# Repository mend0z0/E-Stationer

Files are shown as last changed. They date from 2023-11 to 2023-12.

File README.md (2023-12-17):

## Latest update

``
Working on the scheduling, hardware design, correcting diagrams, and...
``

# E-Stationer

E-Stationer is a project of consisting of two hardware parts, E-Pen and E-Paper, and 1 software parts that allow the user
to draw, write, read, and any sort of activities that you are able to do with a typical pen and paper.

## Features

- 
- 
- 

## Tech Stack

### Hardware

- **MCU:** 8bit PIC

- **Connection:** USB, UART, SPI, ADC, GPIO

- **PCB Layers:** 2Layers (None-controlled Impedance)

- **CAD:** KiCAD

### Firmware

- **OS:** State-machine

- **Programming Language:** C

- **IDE:** MPLABX IDE

### Application

- **Application:** Qt6

## WBS Chart

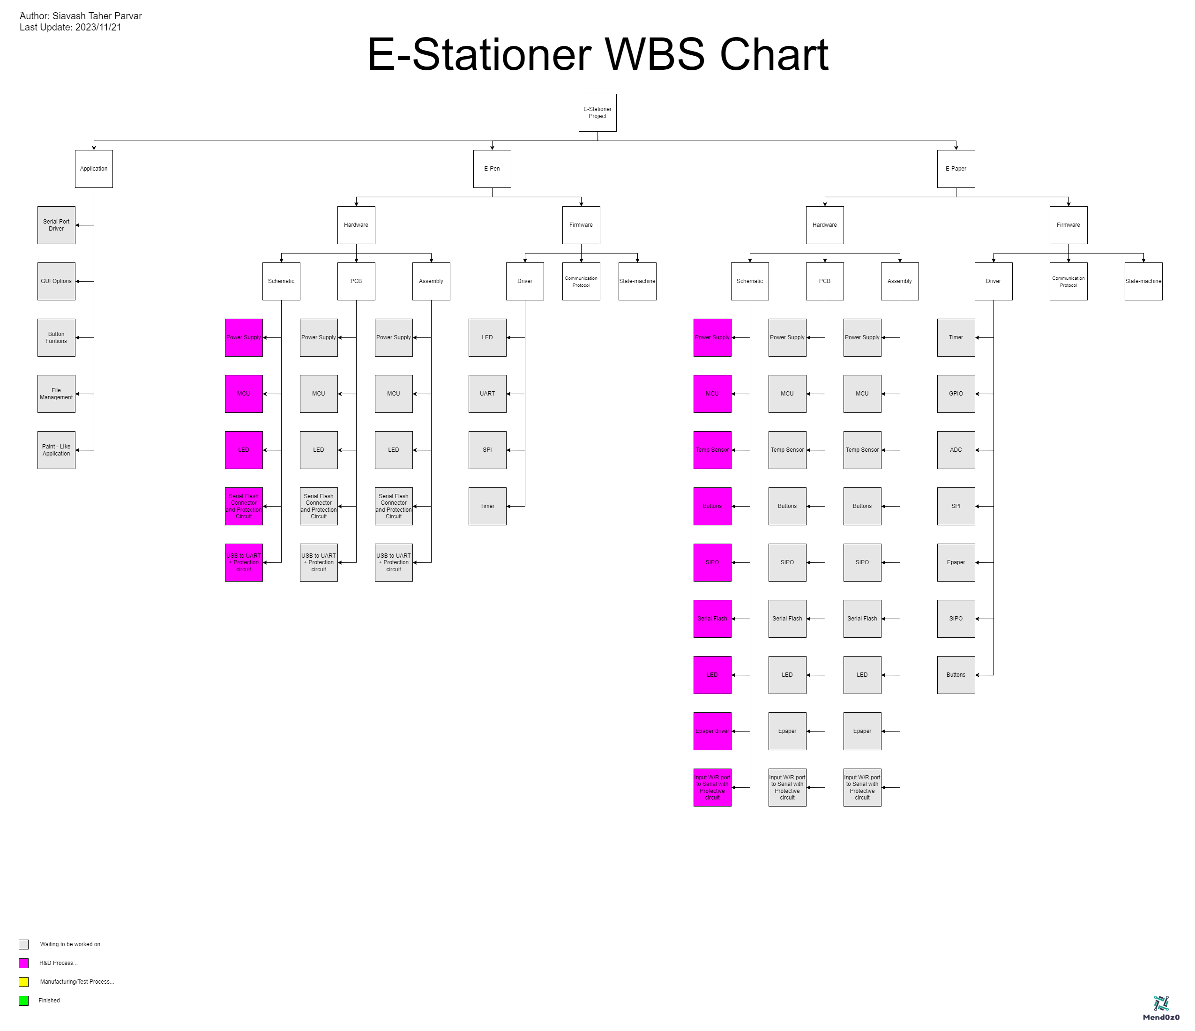
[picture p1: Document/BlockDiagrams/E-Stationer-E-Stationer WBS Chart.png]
WBS Chart


## Block Diagrams

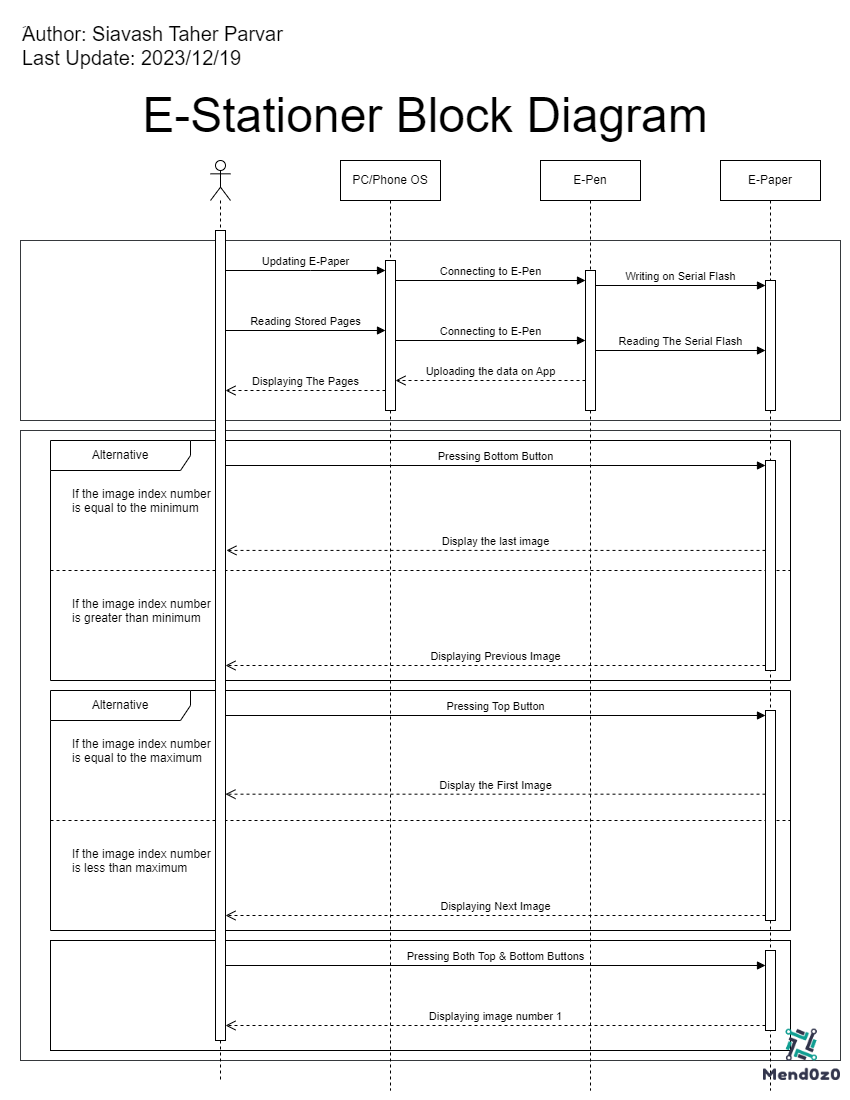
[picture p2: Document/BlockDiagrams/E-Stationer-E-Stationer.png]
E-Stationer Bloc kDiagaram


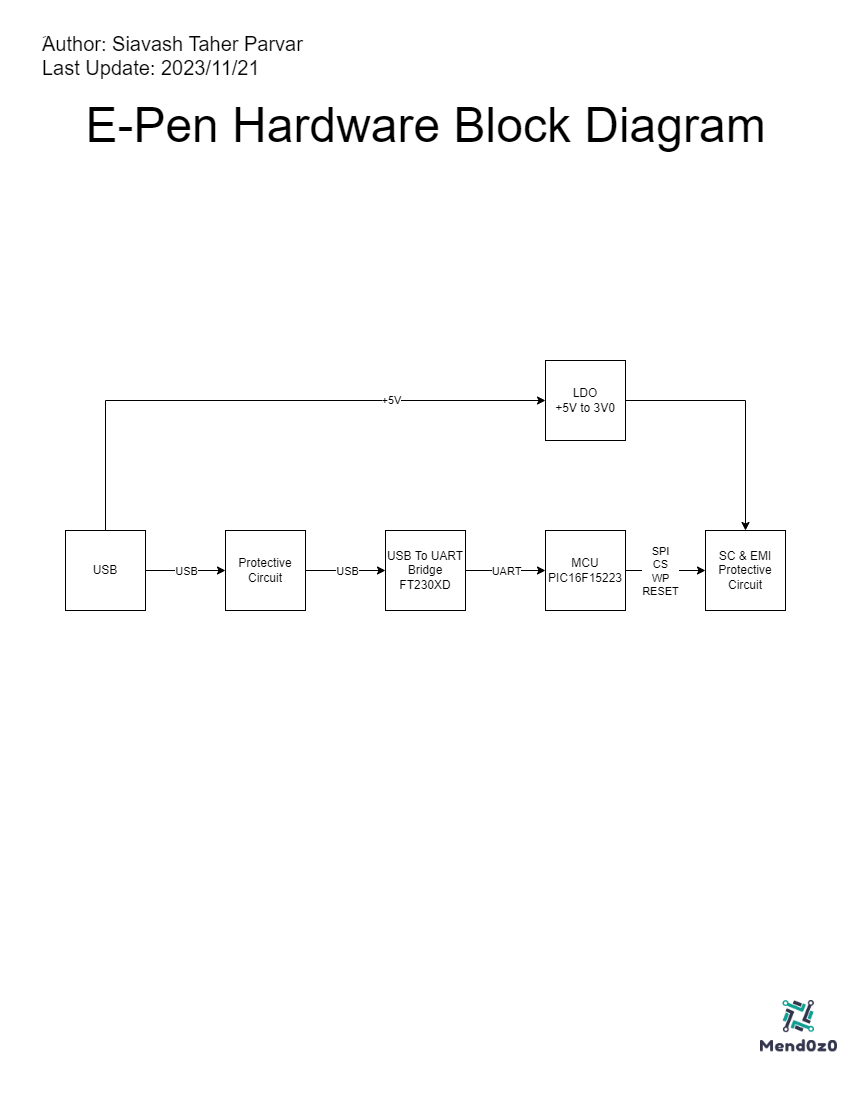
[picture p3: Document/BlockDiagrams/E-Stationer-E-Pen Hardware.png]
E-Pen Hardware Block Diagram


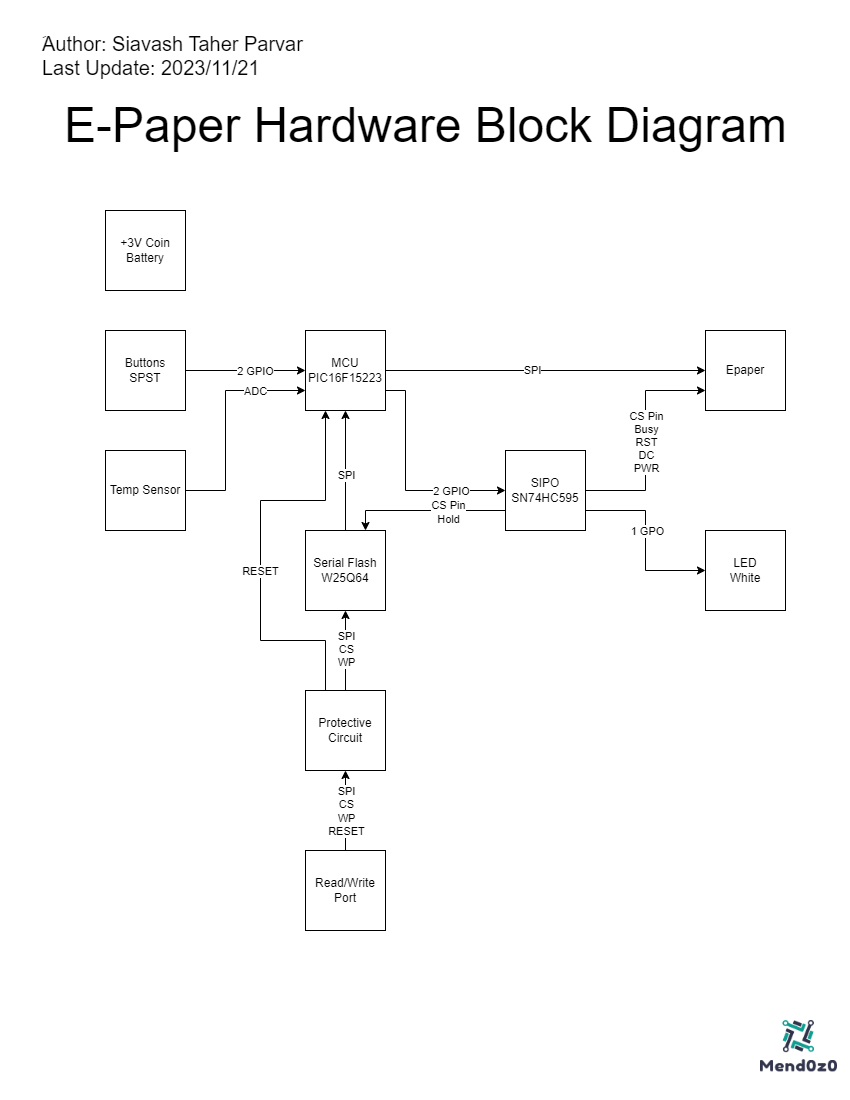
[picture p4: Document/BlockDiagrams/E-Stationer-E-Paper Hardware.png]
E-Paper Hardware Block Diagram


## Screenshots

### Hardware

#### 3D_View

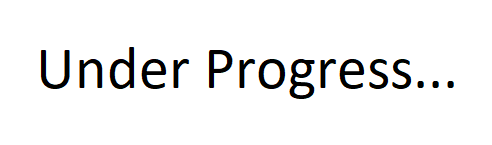
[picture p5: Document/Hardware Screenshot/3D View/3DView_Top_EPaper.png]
3DView_Top_EPaper


3DView_Bottom_EPaper

3DView_Top_EPen

3DView_Bottom_EPen
 
#### Assembled Hardware

Hardware_Top_EPaper

Hardware_Bottom_EPaper

Hardware_Top_EPen

Hardware_Bottom_EPen

### Application
App Screenshot

## Demo

Insert gif or link to demo, it'll be my youtube channel

## LOGO

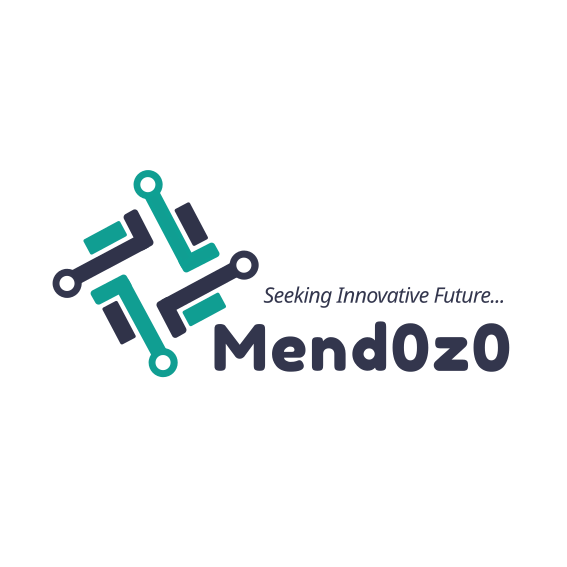
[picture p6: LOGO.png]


## Author

- [@Siavash Taher Parvar](https://www.linkedin.com/in/mend0z0)

## Support

[Support Link](https://github.com/sponsors/mend0z0)

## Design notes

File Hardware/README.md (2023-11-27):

# _SUB_HW_EPaper

- __What is this board?__ This board will display the stored picture on the serial flash eeprom.
- __How will this board communicate?__ This eeprom on this board will be programmed by provided SPI pin. While it's under programming the MCU will be kept at reset state.

## Features

- __MCU :__ PIC16F15223 
- __Inputs :__ SPI
- __Outputs :__ E-ink Display
- __Board Osc. Freq. :__ 32 MHz (Internal)
- __Working Voltage :__ 3VDC (Coin battery)
- __Current Consumption :__ N/A
- __Board Dimensions :__ N/A

# _SUB_HW_EPen

- __What is this board?__ This board will be used to write on the EPaper serial flash.
- __How will this board communicate?__ The data that has to be written on Epaper serial flash will be received from USB and it'll be written over SPI bus.

## Features

- __MCU :__ PIC16F15223 
- __Inputs :__ USB
- __Outputs :__ SPI
- __Board Osc. Freq. :__ 32 MHz (Internal)
- __Working Voltage :__ 5.5VDC (Powered by USB)
- __Current Consumption :__ N/A
- __Board Dimensions :__ N/A

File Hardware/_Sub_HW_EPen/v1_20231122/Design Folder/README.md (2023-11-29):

# TODO list

This todo list belongs to _SUB_HW_EPen, the hardware part of EPen sub project. 

## Tasks

- #### MUST to DO :
    - Writing the LED indicator status once it's been determined how it should blink based on different situation.
    - Adding proper screw component and link in mechanical page
    - Adding a good enclosure 
	- Adding the PCB and it's size to mechanical page
	- Adding 3D model for USB footprint (P/N: 10118194-0001LF) 
- #### Important :
    - List the works that efficient and optimized functionality of project depends on these tasks
    -
    - 
- #### General :
    - List tasks that are good to be done but the functionality of project doesn't depend on these
    -
    -

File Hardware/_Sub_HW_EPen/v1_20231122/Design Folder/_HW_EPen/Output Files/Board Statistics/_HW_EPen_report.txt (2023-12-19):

PCB statistics report
=====================
- Date: 12/19/2023 7:22:40 AM
- Project: _HW_EPen
- Board name: _HW_EPen

Board
-----
- Width: 1950.00 mils
- Height: 1150.00 mils
- Area: 2233839.53 mils²

Pads
----
- Through hole: 29
- SMD: 158
- Connector: 0
- NPTH: 0

Vias
----
- Through vias: 58
- Blind/buried: 0
- Micro vias: 0

Components
----------

| | Front Side | Back Side | Total |
|---|---|---|---|
|THT: | 2 | 0 | 2 |
|SMD: | 50 | 0 | 50 |
|Unspecified:  | 5 | 0 | 5 |
|Total: | 57 | 0 | 57 |

Drill holes
-----------

| Count | Shape | X Size | Y Size | Plated | Via/Pad | Start Layer | Stop Layer |
|---|---|---|---|---|---|---|---|
| 58 | Round |  15.75 mils |  15.75 mils | PTH | Via | F.Cu | B.Cu |
| 12 | Round |  39.37 mils |  39.37 mils | PTH | Pad | F.Cu | B.Cu |
| 9 | Round |  11.81 mils |  11.81 mils | PTH | Pad | F.Cu | B.Cu |
| 4 | Round | 106.30 mils | 106.30 mils | PTH | Pad | F.Cu | B.Cu |
| 2 |  Slot |  19.69 mils |  45.28 mils | PTH | Pad | F.Cu | B.Cu |
| 2 |  Slot |  33.46 mils |  21.65 mils | PTH | Pad | F.Cu | B.Cu |

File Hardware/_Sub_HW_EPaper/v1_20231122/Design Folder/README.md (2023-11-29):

# TODO list

A brief description of this todo list belongs to what project

## Tasks

- #### MUST to DO :
    - Adding 3D part to the 8-SOIC footprint for serial flash
    -
    - 
- #### Important :
    - List the works that efficient and optimized functionality of project depends on these tasks
    -
    - 
- #### General :
    - List tasks that are good to be done but the functionality of project doesn't depend on these
    -
    -

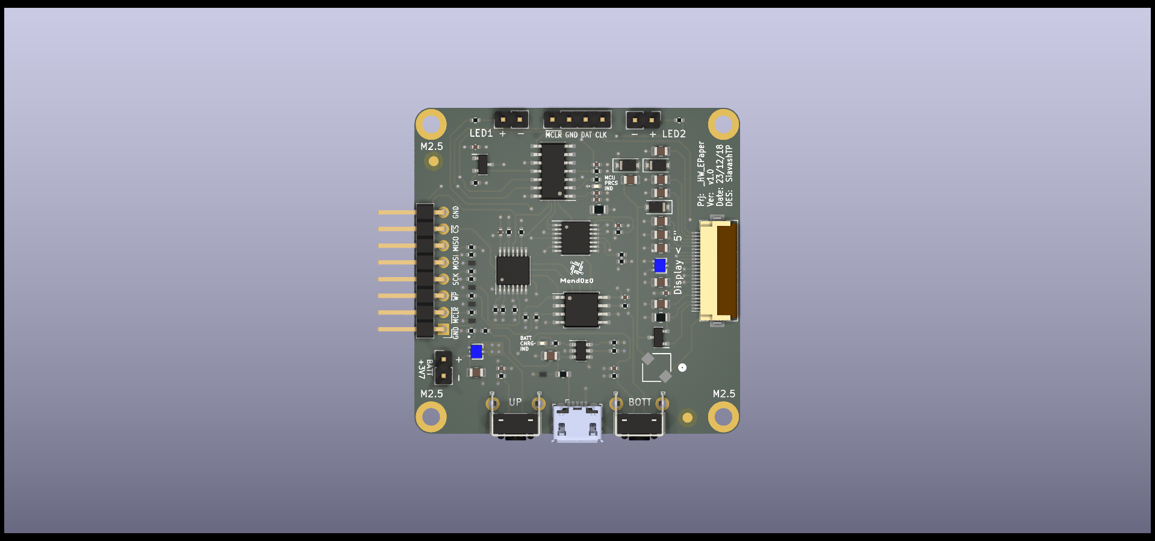
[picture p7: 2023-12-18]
Hardware/_Sub_HW_EPaper/v1_20231122/Released Folder/vX.Y - YYYYMMDD/3D/3D View Pic/_HW_EPaper_Top.png

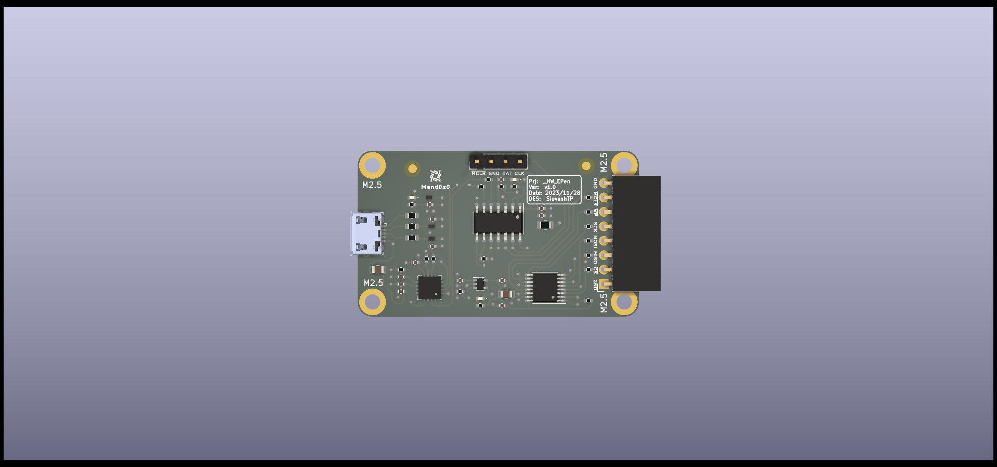
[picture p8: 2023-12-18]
Hardware/_Sub_HW_EPen/v1_20231122/Released Folder/vX.Y - YYYYMMDD/3D/3D View Pic/_HW_EPen_Top.png

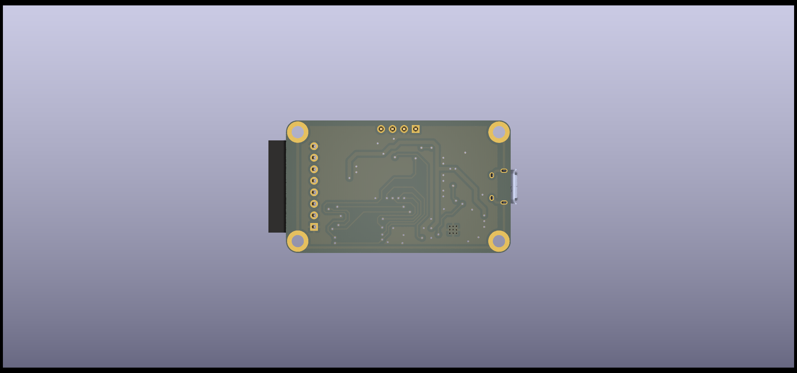
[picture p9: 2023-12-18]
Hardware/_Sub_HW_EPen/v1_20231122/Released Folder/vX.Y - YYYYMMDD/3D/3D View Pic/_HW_EPen_Bottom.png

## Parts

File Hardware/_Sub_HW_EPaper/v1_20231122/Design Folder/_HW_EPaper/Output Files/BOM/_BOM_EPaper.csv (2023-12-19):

null | Sourced | Placed | References | Value | Footprint | Link | Description | Manufacturer | Part Number (Manufacturer) | Part Number (Vendor) | Vendor | Quantity
1 |  |  | C701, C702, C704, C705, C706, C707, C708, C709, C710, C1001, C1002 | 4u7F_16V | C_0805_2012Metric | https://www.digikey.ca/en/products/detail/murata-electronics/GRM21BR71C475KE51L/6606095 | 4.7 µF ±10% 16V Ceramic Capacitor X7R 0805 (2012 Metric) | Murata Electronics | GRM21BR71C475KE51L | 490-14466-2-ND | Digikey | 11
2 |  |  | C302, C401, C501, C601, C801, C802, C901 | 1uF_10V_X7R | C_0402_1005Metric | https://www.digikey.ca/en/products/detail/murata-electronics/GRM155Z71A105KE01D/13905035 | 1 µF ±10% 10V Ceramic Capacitor X7R 0402 (1005 Metric) | Murata Electronics | GRM155Z71A105KE01D | 490-GRM155Z71A105KE01DTR-ND | Digikey | 7
3 |  |  | C301, C303, C703 | 100nF_50V | C_0402_1005Metric | https://www.digikey.ca/en/products/detail/murata-electronics/GRM155R71H104KE14J/4905180 | 0.1 µF ±10% 50V Ceramic Capacitor X7R 0402 (1005 Metric) | Murata Electronics | GRM155R71H104KE14J | 490-13342-2-ND | Digikey | 3
4 |  |  | R301, R401, R402, R403, R501, R502, R505, R506, R507, R508, R509, R601, R703, R801, R802, R901, R1003, R1005 | 10kR_1/16W_1% | R_0402_1005Metric | https://www.digikey.ca/en/products/detail/bourns-inc/CR0402-FX-1002GLF/3593192 | 10 kOhms ±1% 0.063W, 1/16W Chip Resistor 0402 (1005 Metric) Thick Film | Bourns Inc. | CR0402-FX-1002GLF | CR0402-FX-1002GLFTR-ND | Digikey | 18
5 |  |  | R503, R504, R510, R511 | 27R_1/16W_1% | R_0402_1005Metric | https://www.digikey.ca/en/products/detail/bourns-inc/CR0402-FX-27R0GLF/3783280 | 27 Ohms ±1% 0.063W, 1/16W Chip Resistor 0402 (1005 Metric) Thick Film | Bourns Inc. | CR0402-FX-27R0GLF | CR0402-FX-27R0GLFTR-ND | Digikey | 4
6 |  |  | R302, R702, R1004 | 470R_1/16W_1% | R_0402_1005Metric | https://www.digikey.ca/en/products/detail/bourns-inc/CR0402-FX-4700GLF/3783391 | 470 Ohms ±1% 0.063W, 1/16W Chip Resistor 0402 (1005 Metric) Thick Film | Bourns Inc. | CR0402-FX-4700GLF | CR0402-FX-4700GLFTR-ND | Digikey | 3
7 |  |  | R1001, R1101, R1102 | 100R_1/10W_1% | R_0402_1005Metric | https://www.digikey.ca/en/products/detail/koa-speer-electronics-inc/RK73H1ETTP1000F/9844157 | 100 Ohms ±1% 0.1W, 1/10W Chip Resistor 0402 (1005 Metric) Automotive AEC-Q200, Moisture Resistant Thick Film | KOA Speer Electronics, Inc. | RK73H1ETTP1000F | 2019-RK73H1ETTP1000FTR-ND | Digikey | 3
8 |  |  | R303 | 1R_1/4W_1% | R_0805_2012Metric | https://www.digikey.ca/en/products/detail/stackpole-electronics-inc/RNCP0805FTD1R00/2240195 | 1 Ohms ±1% 0.25W, 1/4W Chip Resistor 0805 (2012 Metric) Anti-Sulfur Thin Film | Stackpole Electronics Inc | RNCP0805FTD1R00 | RNCP0805FTD1R00TR-ND | Digikey | 1
9 |  |  | R701 | 0.47R_1/8W_5% | R_0805_2012Metric | https://www.digikey.ca/en/products/detail/cts-resistor-products/73L3R47J/1543464 | 470 mOhms ±5% 0.125W, 1/8W Chip Resistor 0805 (2012 Metric) Current Sense Thick Film | CTS Resistor Products | 73L3R47J | 73L3R47JTR-ND | Digikey | 1
10 |  |  | R1002 | 30kR_1/16W_1% | R_0402_1005Metric | https://www.digikey.ca/en/products/detail/bourns-inc/CR0402-FX-3002GLF/3783296 | 30 kOhms ±1% 0.063W, 1/16W Chip Resistor 0402 (1005 Metric) Thick Film | Bourns Inc. | CR0402-FX-3002GLF | CR0402-FX-3002GLFTR-ND | Digikey | 1
11 |  |  | L701 | 10uH_600mA | IND_CDRH3D11HPNP-100NC_SUM | https://www.digikey.ca/en/products/detail/sumida-america-inc/CDRH3D11HPNP-100NC/3947130 | 10 µH Shielded Inductor 600 mA 413mOhm Max Nonstandard | Sumida America Components Inc. | CDRH3D11HPNP-100NC | 308-1966-2-ND | Digikey | 1
12 |  |  | D501, D502, D503, D504, D1001 | TVS_6.5V_3A | CR_7PCT_L3F_TOS | https://www.digikey.ca/en/products/detail/good-ark-semiconductor/GSEWT5B003/18667485 | 20.5V Clamp 3A (8/20µs) Ipp Tvs Diode Surface Mount SOD-882 | Good-Ark Semiconductor | GSEWT5B003 | 4786-GSEWT5B003TR-ND | Digikey | 5
13 |  |  | D701, D702, D703 | SS2040FL | D_SOD-123F | https://www.digikey.ca/en/products/detail/panjit-international-inc/SS2040FL-R1-00001/14660034 | Diode 40 V 2A Surface Mount SOD-123FL | Panjit International Inc. | SS2040FL_R1_00001 | 3757-SS2040FL_R1_00001TR-ND | Digikey | 3
14 |  |  | U301 | PIC16F15223_8BIT | SO-14_3.9x8.65mm_P1.27mm | https://www.digikey.ca/en/products/detail/microchip-technology/PIC16F15223-E-SL/12807315 | PIC PIC® 16F, Functional Safety (FuSa) Microcontroller IC 8-Bit 32MHz 3.5KB (2K x 14) FLASH 14-SOIC | Microchip Technology | PIC16F15223-E/SL | 150-PIC16F15223-E/SL-ND | Digikey | 1
15 |  |  | U401 | W25Q64JVSSIQ | SOIC-8_5.275x5.275mm_P1.27mm | https://www.digikey.ca/en/products/detail/winbond-electronics/W25Q64JVSSIQ/5803992 | FLASH - NOR Memory IC 64Mbit SPI - Quad I/O 133 MHz 8-SOIC | Winbond Electronics | W25Q64JVSSIQ | W25Q64JVSSIQ-ND | Digikey | 1
16 |  |  | U501 | SN74HCS32PWR | TSSOP-14_4.4x5mm_P0.65mm | https://www.digikey.ca/en/products/detail/texas-instruments/SN74HCS32PWR/11625401 | OR Gate IC 4 Channel Schmitt Trigger Input 14-TSSOP | Texas Instruments | SN74HCS32PWR | 296-SN74HCS32PWRTR-ND | Digikey | 1
17 |  |  | U601 | 74VHC164FT | TSSOP-14_4.4x5mm_P0.65mm | https://www.digikey.ca/en/products/detail/toshiba-semiconductor-and-storage/74VHC164FT/5019930 | Shift Shift Register 1 Element 8 Bit 14-TSSOP | Toshiba Semiconductor and Storage | 74VHC164FT | 264-74VHC164FTTR-ND | Digikey | 1
18 |  |  | U901 | MCP9700T-E/TT | SOT-23 | https://www.digikey.ca/en/products/detail/microchip-technology/MCP9700T-E-TT/1212510 | Temperature Sensor Analog, Local -40°C ~ 125°C 10mV/°C SOT-23-3 | Microchip Technology | MCP9700T-E/TT | MCP9700T-E/TTTR-ND | Digikey | 1
19 |  |  | U1001 | RT9526AGE | SOT-23-6 | https://www.digikey.ca/en/products/detail/richtek-usa-inc/RT9526AGE/5820110 | Charger IC Lithium Ion SOT-23-6 | Richtek USA Inc. | RT9526AGE | 1028-1359-2-ND | Digikey | 1
20 |  |  | F1001 | 100mA_15V_0.5R | Fuse_0603_1608Metric | https://www.digikey.ca/en/products/detail/eaton-electronics-division/PTS060315V010/15193506 | PTC Resettable Fuse 15V 100 mA Ih Surface Mount 0603 (1608 Metric), Concave | Eaton - Electronics Division | PTS060315V010 | 283-PTS060315V010TR-ND | Digikey | 1
21 |  |  | SW801, SW802 | SPST-NO | SW_Tactile_SPST_Angled_PTS645Vx31-2LFS | https://www.digikey.ca/en/products/detail/c-k/PTS645VH31-2-LFS/1146771 | Tactile Switch SPST-NO Side Actuated Through Hole, Right Angle | C&K | PTS645VH31-2 LFS | CKN9118-ND | Digikey | 2
22 |  |  | LED301, LED1001 | RED_2V | LED_0402_1005Metric | https://www.digikey.ca/en/products/detail/harvatek-corporation/B2841USD-20D001014U1930/16729514 | Red 624nm LED Indication - Discrete 2V 0402 (1005 Metric) | Harvatek Corporation | B2841USD-20D001014U1930 | 3147-B2841USD-20D001014U1930TR-ND | Digikey | 2
23 |  |  | Q702, Q1001 | SSM3J117TU,LF | UFM_TOS | https://www.digikey.ca/en/products/detail/toshiba-semiconductor-and-storage/SSM3J117TU-LF/6679146 | P-Channel 30 V 2A (Ta) 500mW (Ta) Surface Mount UFM | Toshiba Semiconductor and Storage | SSM3J117TU,LF | SSM3J117TULFTR-ND | Digikey | 2
24 |  |  | Q701 | AS3400 | SOT-23 | https://www.digikey.ca/en/products/detail/anbon-semiconductor-int-l-limited/AS3400/16708476 | N-Channel 30 V 5.6A (Ta) 1.2W (Ta) Surface Mount SOT-23 | ANBON SEMICONDUCTOR (INT'L) LIMITED | AS3400 | 4530-AS3400TR-ND | Digikey | 1
25 |  |  | J1002, J1101, J1102 | HDR_2POS_VERT | PinHeader_1x02_P2.54mm_Vertical | https://www.digikey.ca/en/products/detail/adam-tech/PH1-02-UA/9830266 | Connector Header Through Hole 2 position 0.100" (2.54mm) | Adam Tech | PH1-02-UA | 2057-PH1-02-UA-ND | Digikey | 3
26 |  |  | J301 | HDR_4POS_VERT | PinHeader_1x04_P2.54mm_Vertical | https://www.digikey.ca/en/products/detail/adam-tech/PH1-04-UA/9829296 | Connector Header Through Hole 4 position 0.100" (2.54mm) | Adam Tech | PH1-04-UA | 2057-PH1-04-UA-ND | Digikey | 1
27 |  |  | J501 | HDR_8POS_RA | PinHeader_1x08_P2.54mm_Horizontal | https://www.digikey.ca/en/products/detail/adam-tech/PH1RB-08-UA/9831008 | Connector Header Through Hole, Right Angle 8 position 0.100" (2.54mm) | Adam Tech | PH1RB-08-UA | 2057-PH1RB-08-UA-ND | Digikey | 1
28 |  |  | J701 | FPC_24POS_BOTTOM_0.5P | Hirose_FH12-24S-0.5SH_1x24-1MP_P0.50mm_Horizontal | https://www.digikey.ca/en/products/detail/cvilux-usa/CF35242D0RD-NH/15793069 | 24 Position FFC, FPC Connector Contacts, Bottom 0.020" (0.50mm) Surface Mount, Right Angle | Cvilux USA | CF35242D0RD-NH | 2987-CF35242D0RD-NHTR-ND | Digikey | 1
29 |  |  | J1001 | USB_microB_RA | USB_Micro-B_Amphenol_10118194_Horizontal | https://www.digikey.ca/en/products/detail/amphenol-cs-fci/10118194-0001LF/2785389 | USB - micro B USB 2.0 Receptacle Connector 5 Position Surface Mount, Right Angle; Through Hole | Adam Tech | 10118194-0001LF | 2057-PH1RB-08-UA-ND | Digikey | 1

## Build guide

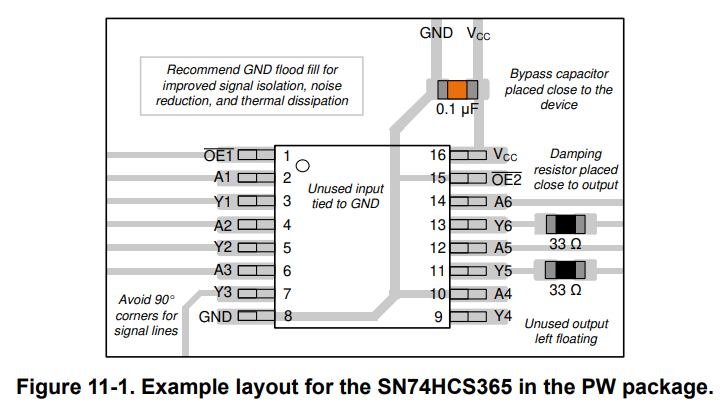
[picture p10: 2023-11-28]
Hardware/_Sub_HW_EPen/v1_20231122/Design Folder/Design Guides/Example layout for the SN74HCS365.png

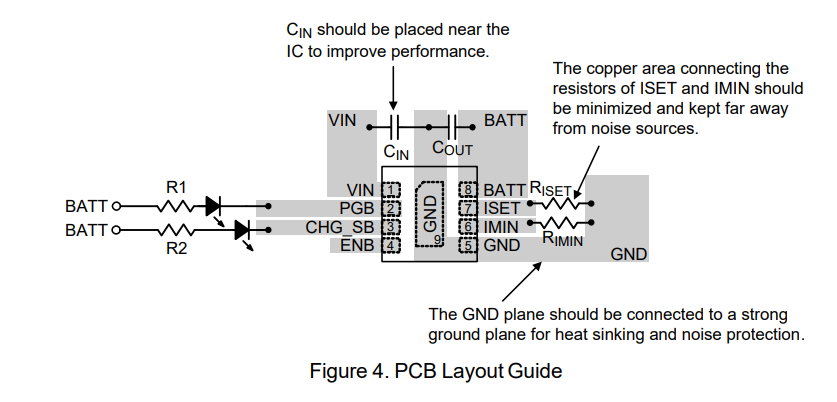
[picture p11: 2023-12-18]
Hardware/_Sub_HW_EPaper/v1_20231122/Design Folder/Design Guides/RT9526A_Layout.png

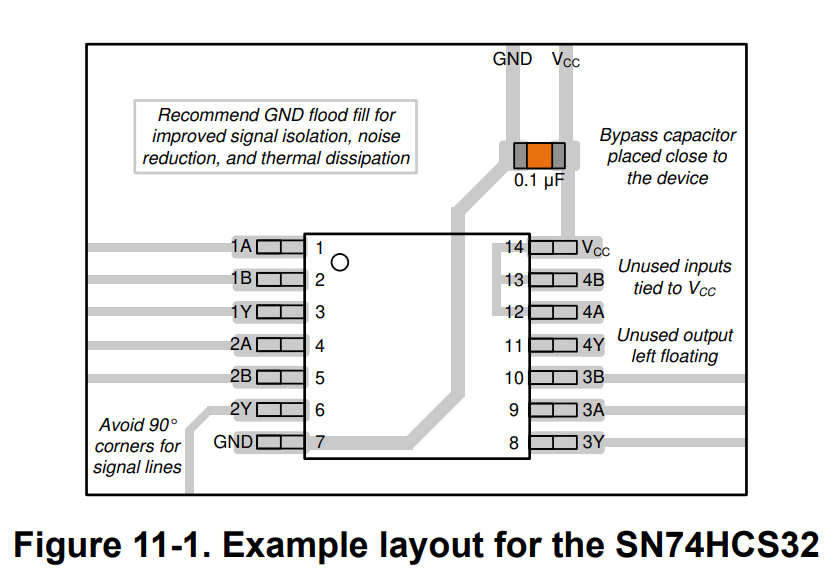
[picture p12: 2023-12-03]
Hardware/_Sub_HW_EPaper/v1_20231122/Design Folder/Design Guides/Screenshot_20231203_104745.png

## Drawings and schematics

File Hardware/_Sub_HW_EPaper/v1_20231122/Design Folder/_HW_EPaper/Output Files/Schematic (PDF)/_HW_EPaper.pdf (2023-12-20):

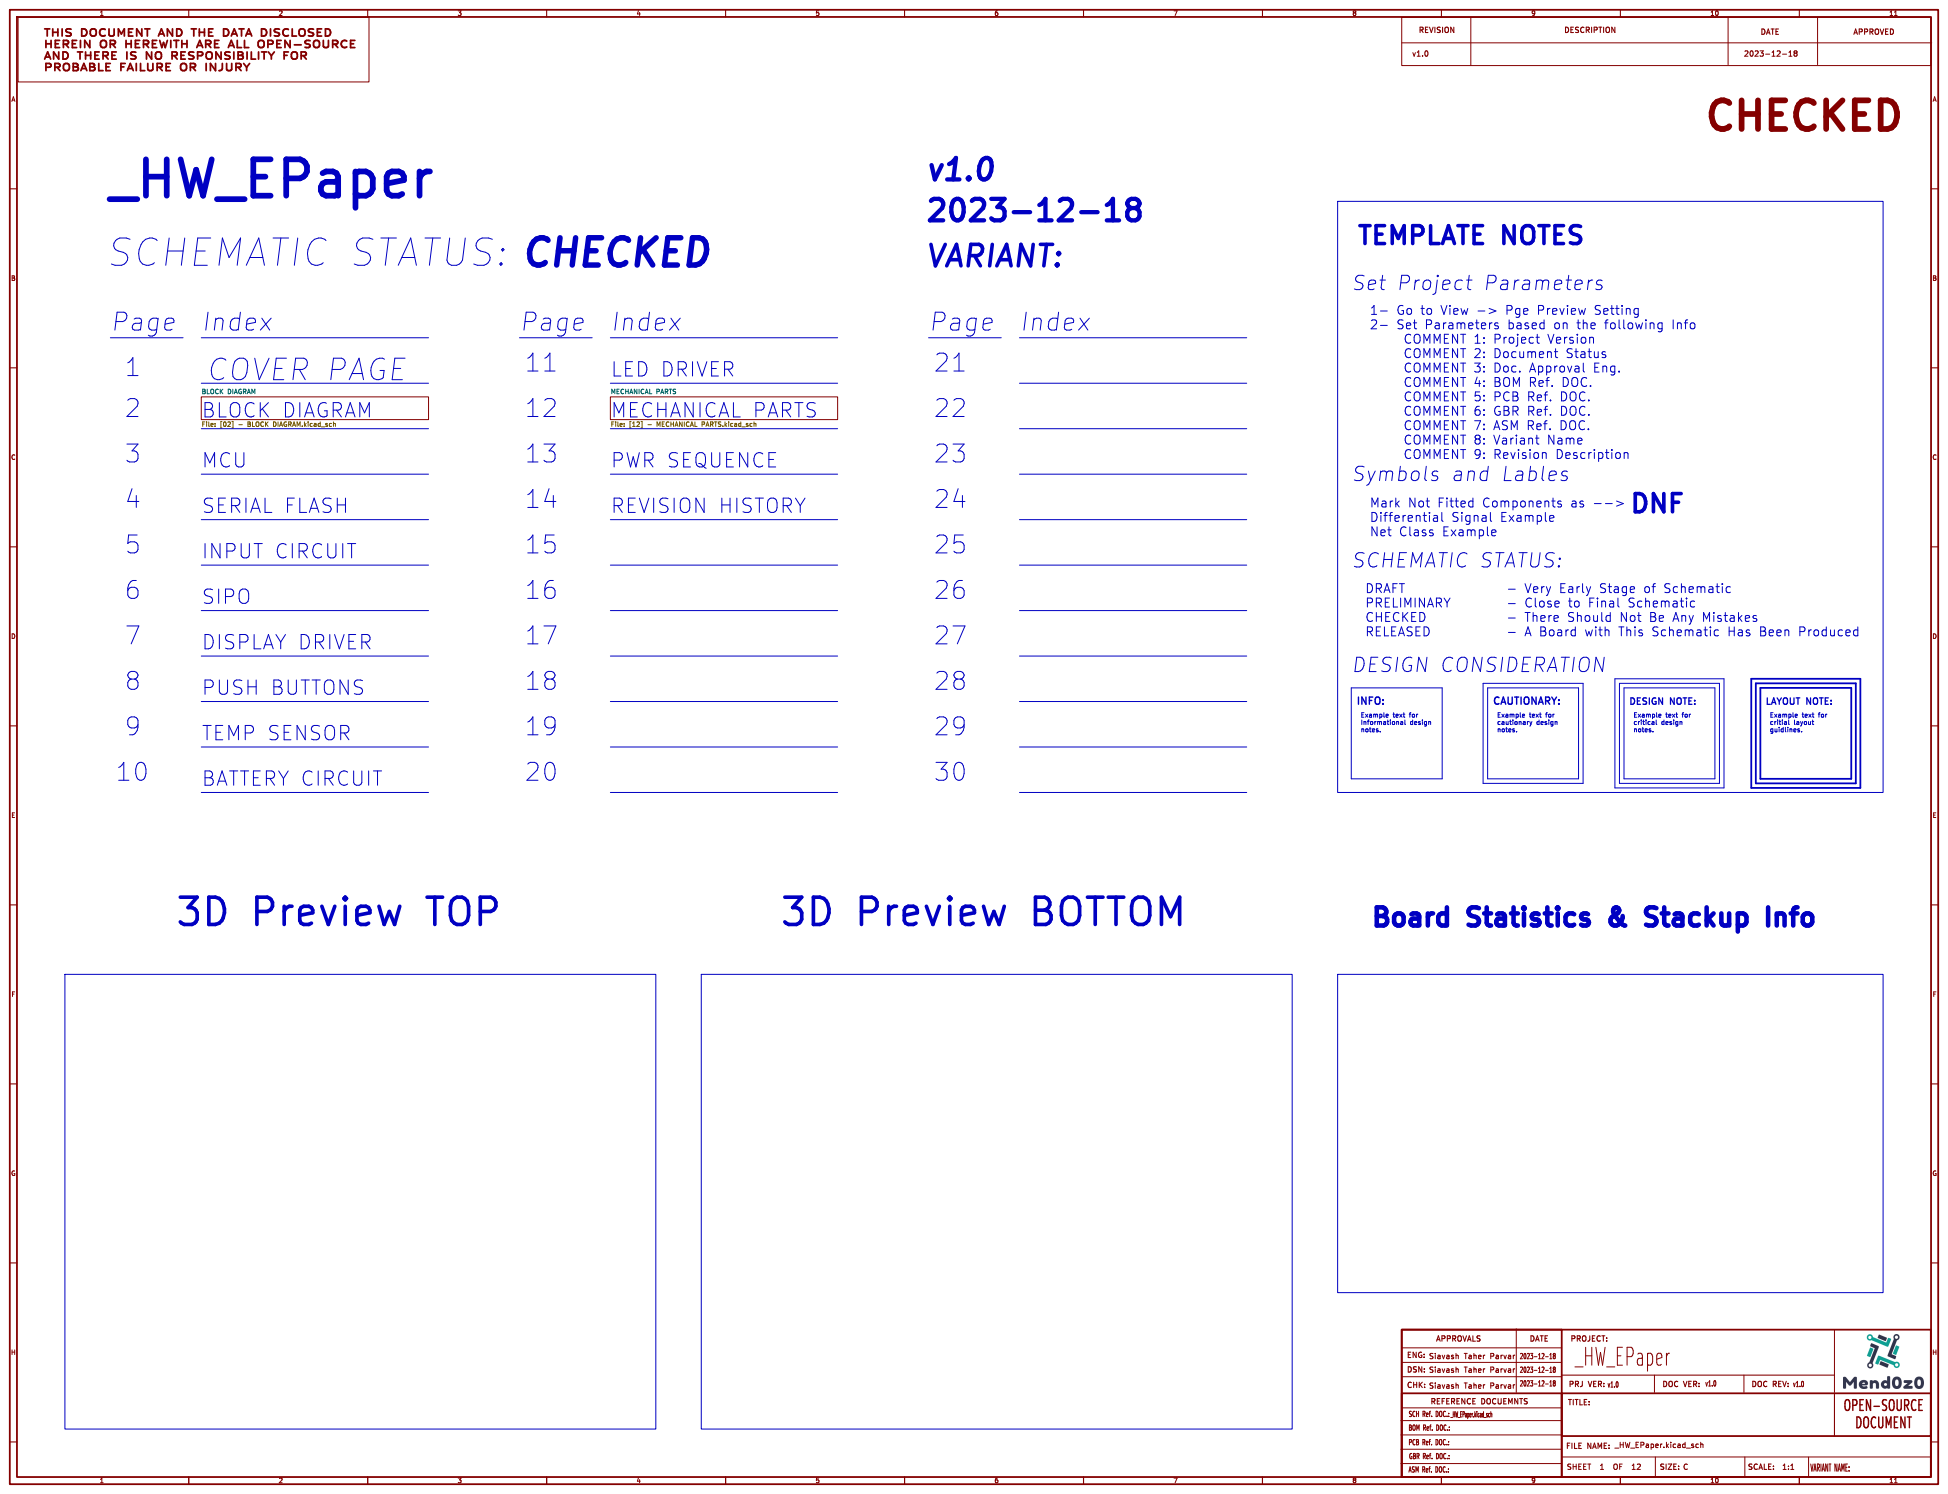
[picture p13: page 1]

1- Go to View -> Pge Preview Setting
Symbols and Lables

Mark Not Fitted Components as -->
Net Class Example
SCHEMATIC STATUS:

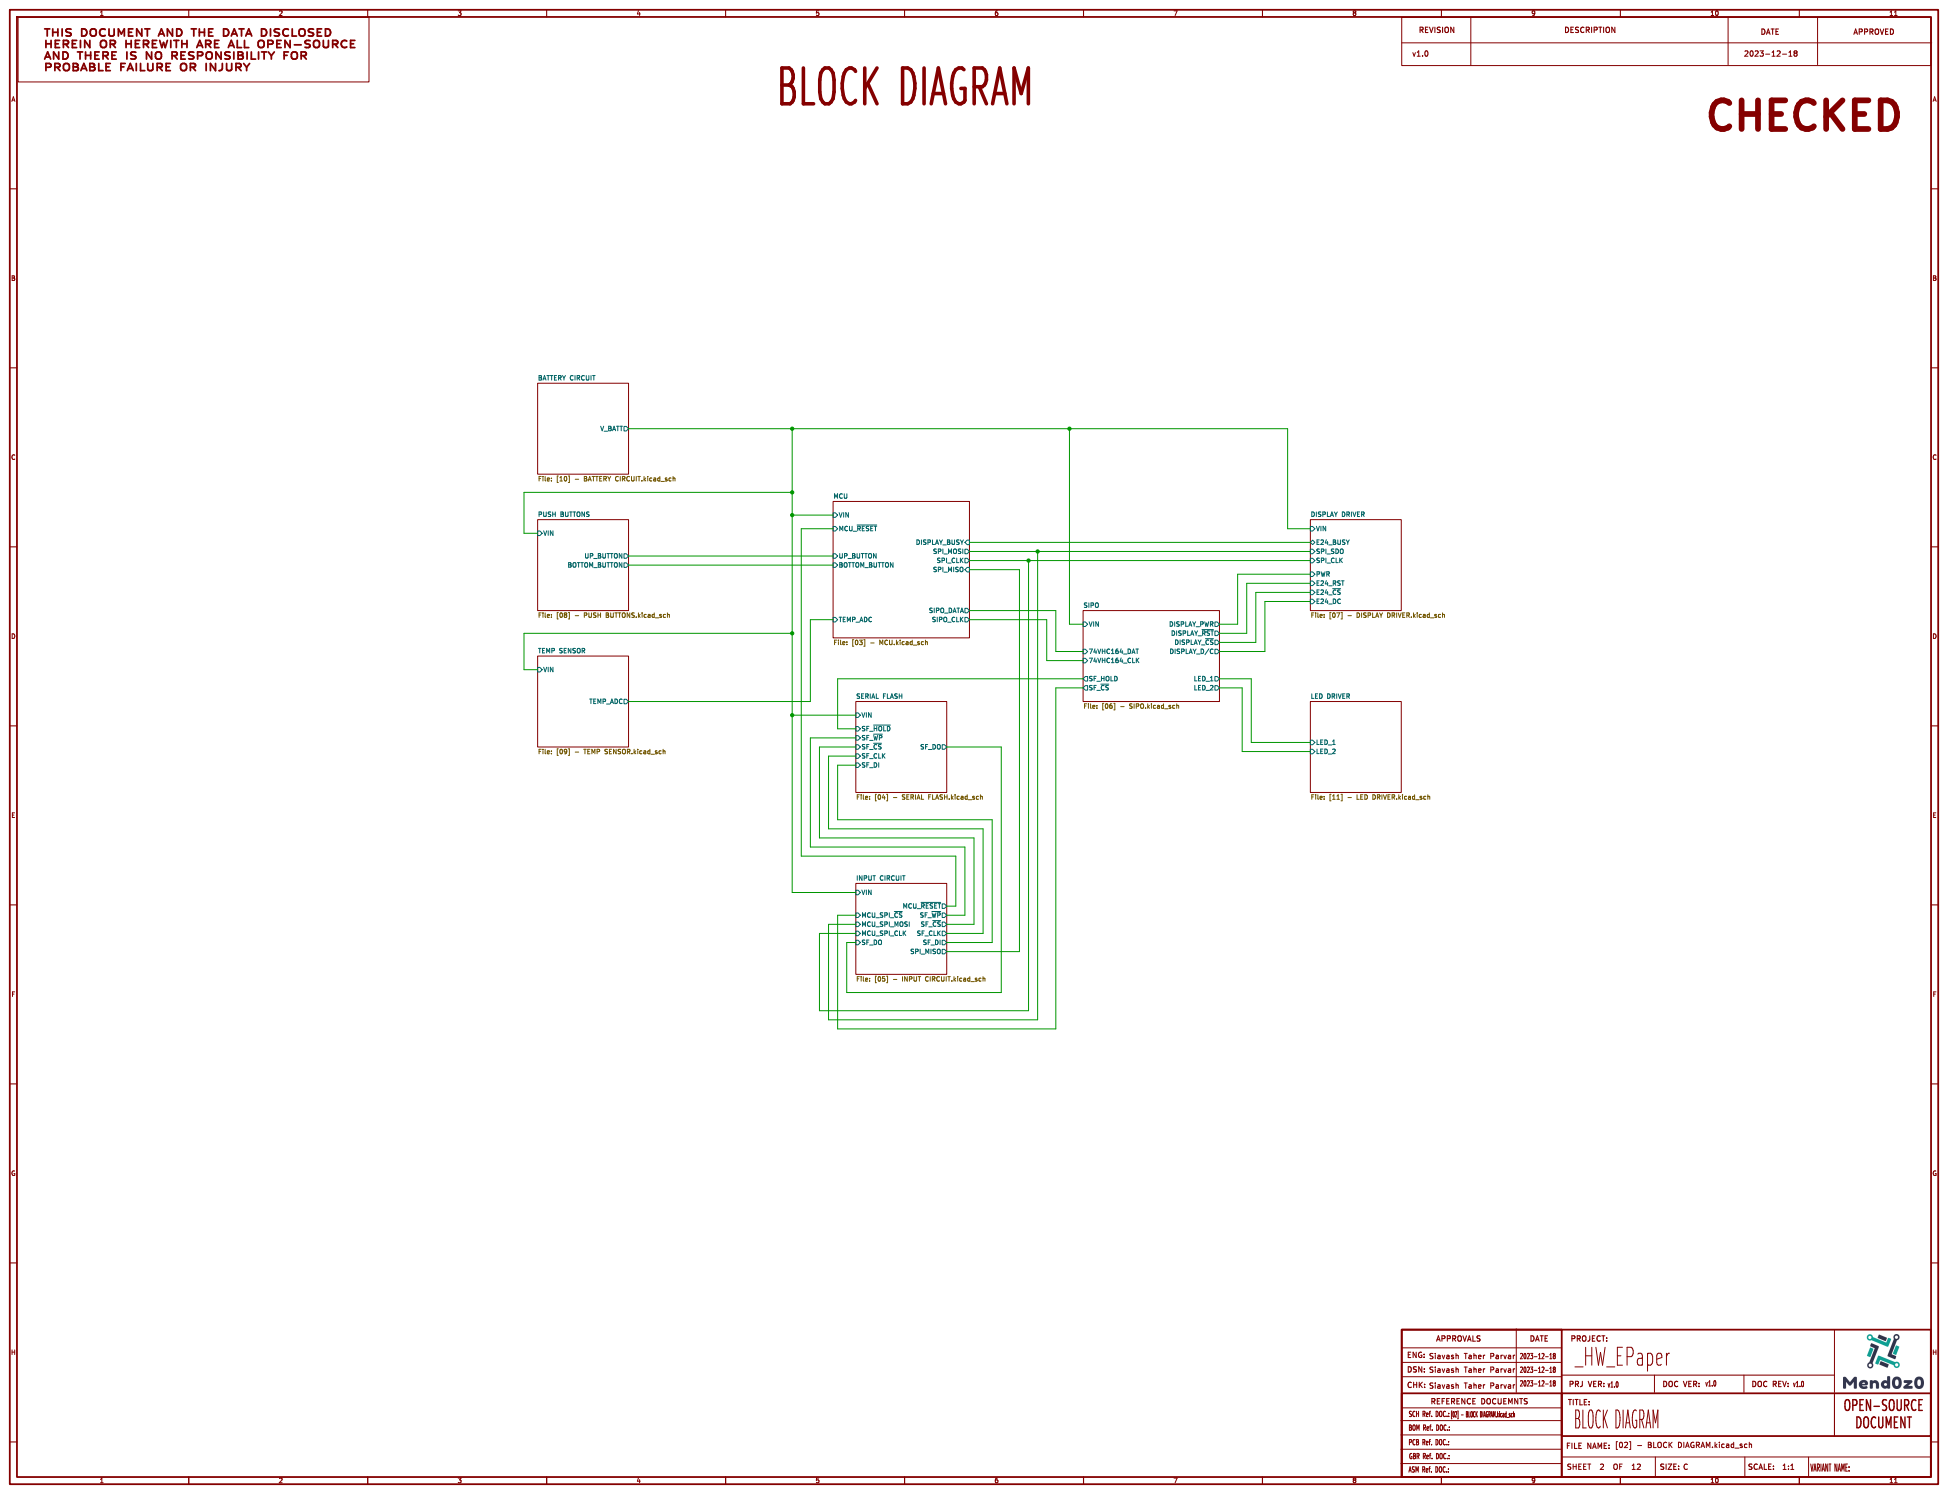
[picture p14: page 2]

File: [08] - PUSH BUTTONS.kicad_sch V_BATT BATTERY CIRCUIT

File: [04] - SERIAL FLASH.kicad_sch VIN

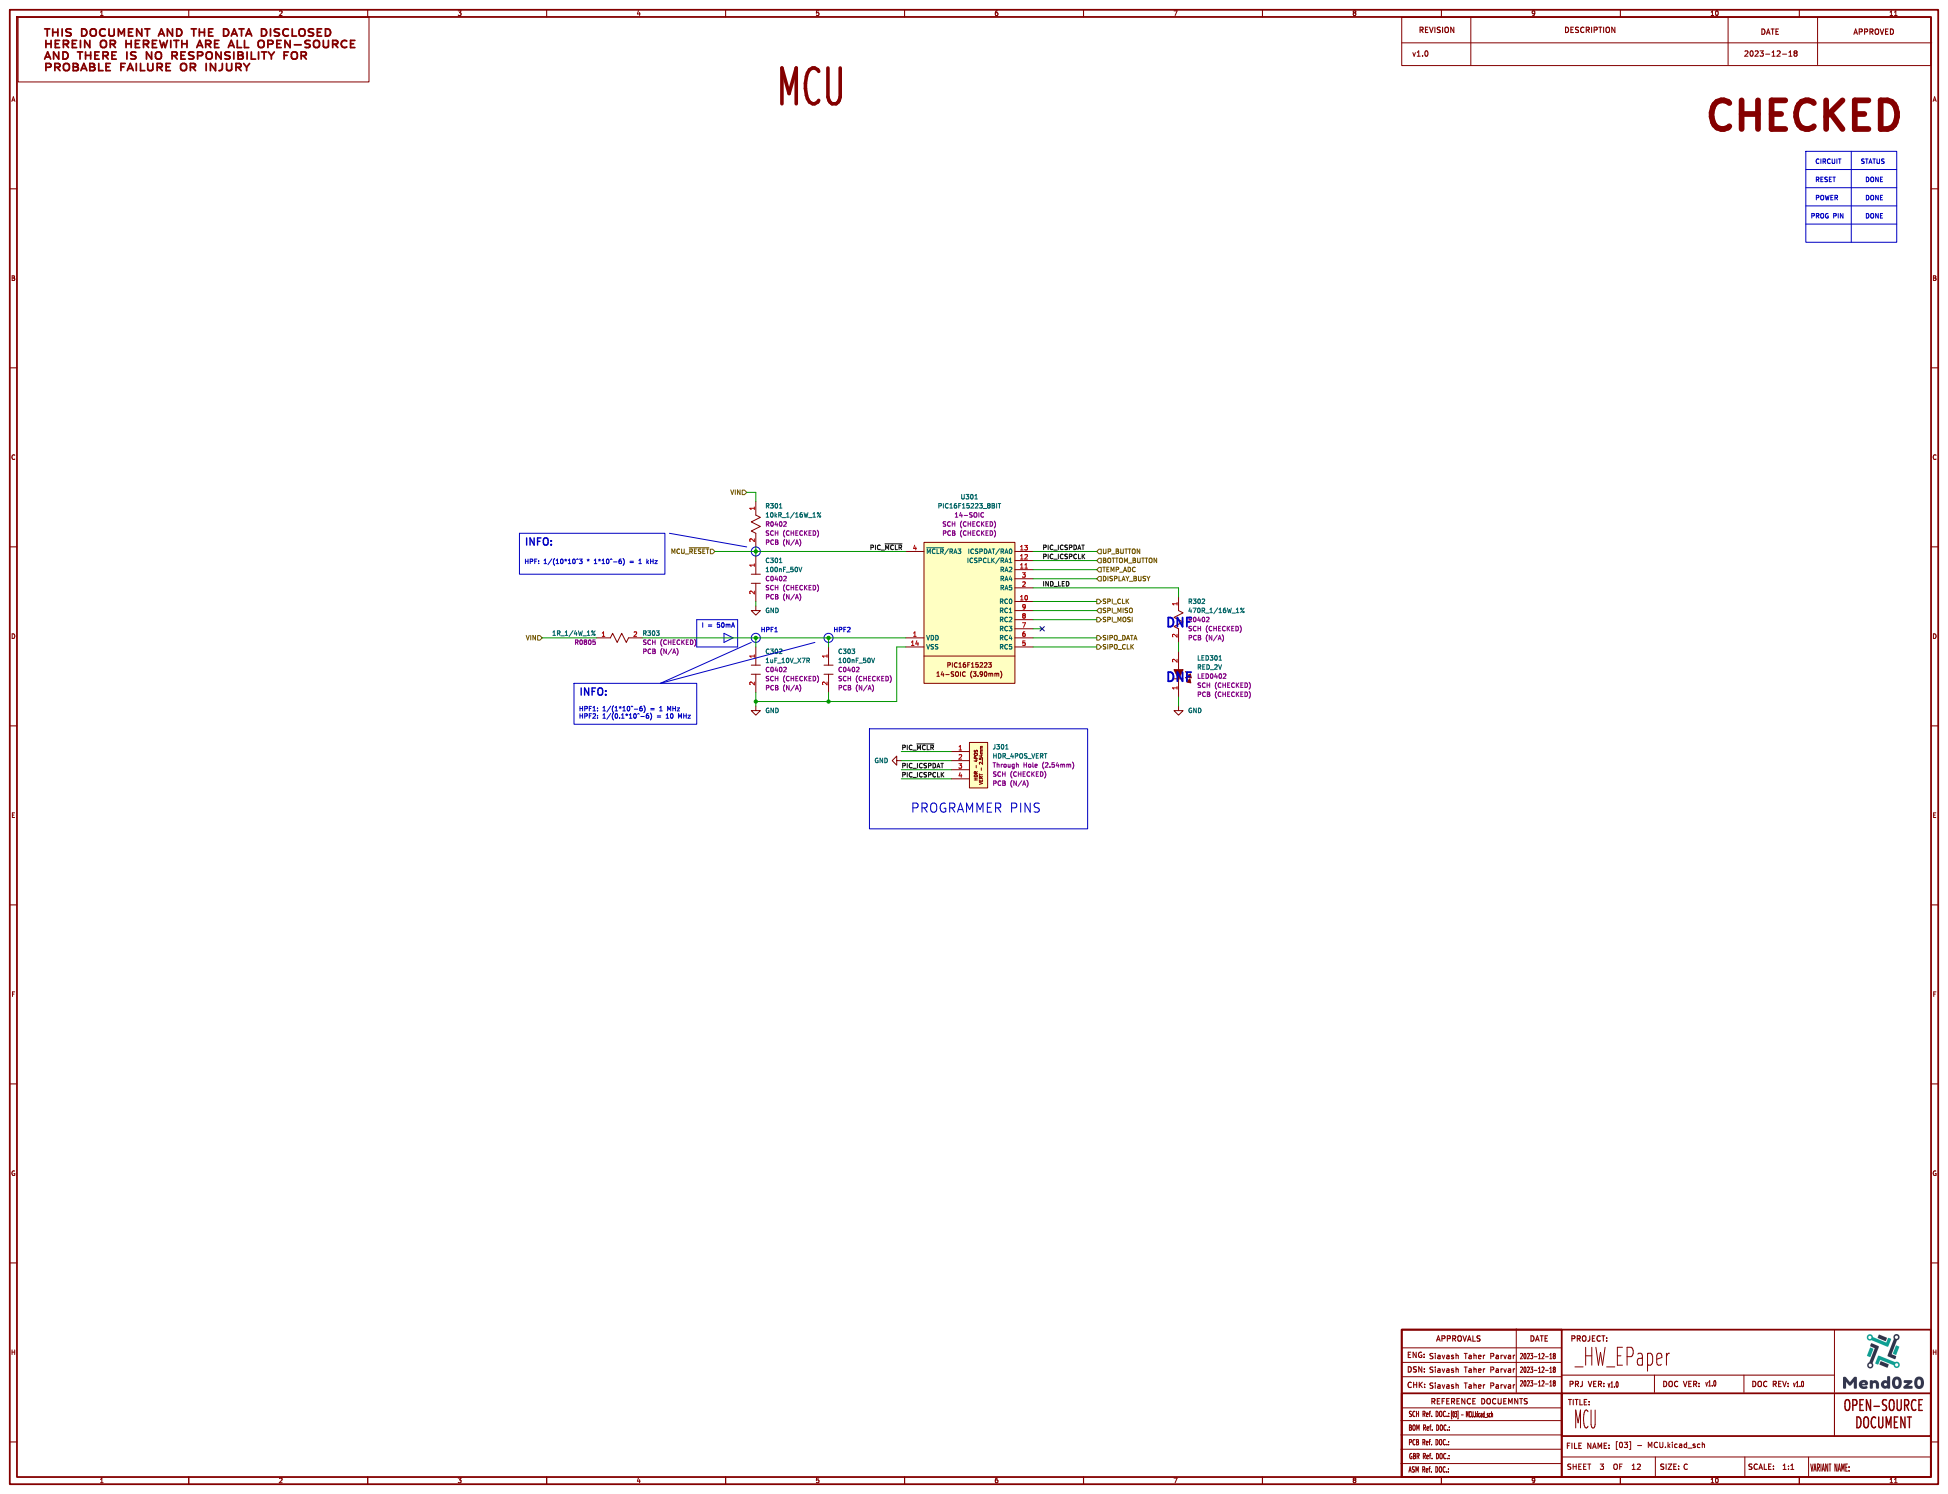
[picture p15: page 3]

Through Hole (2.54mm) SCH (CHECKED) PCB (N/A) GND GND

C0402 SCH (CHECKED) PCB (N/A) GND

LED0402 SCH (CHECKED) PCB (CHECKED) GND

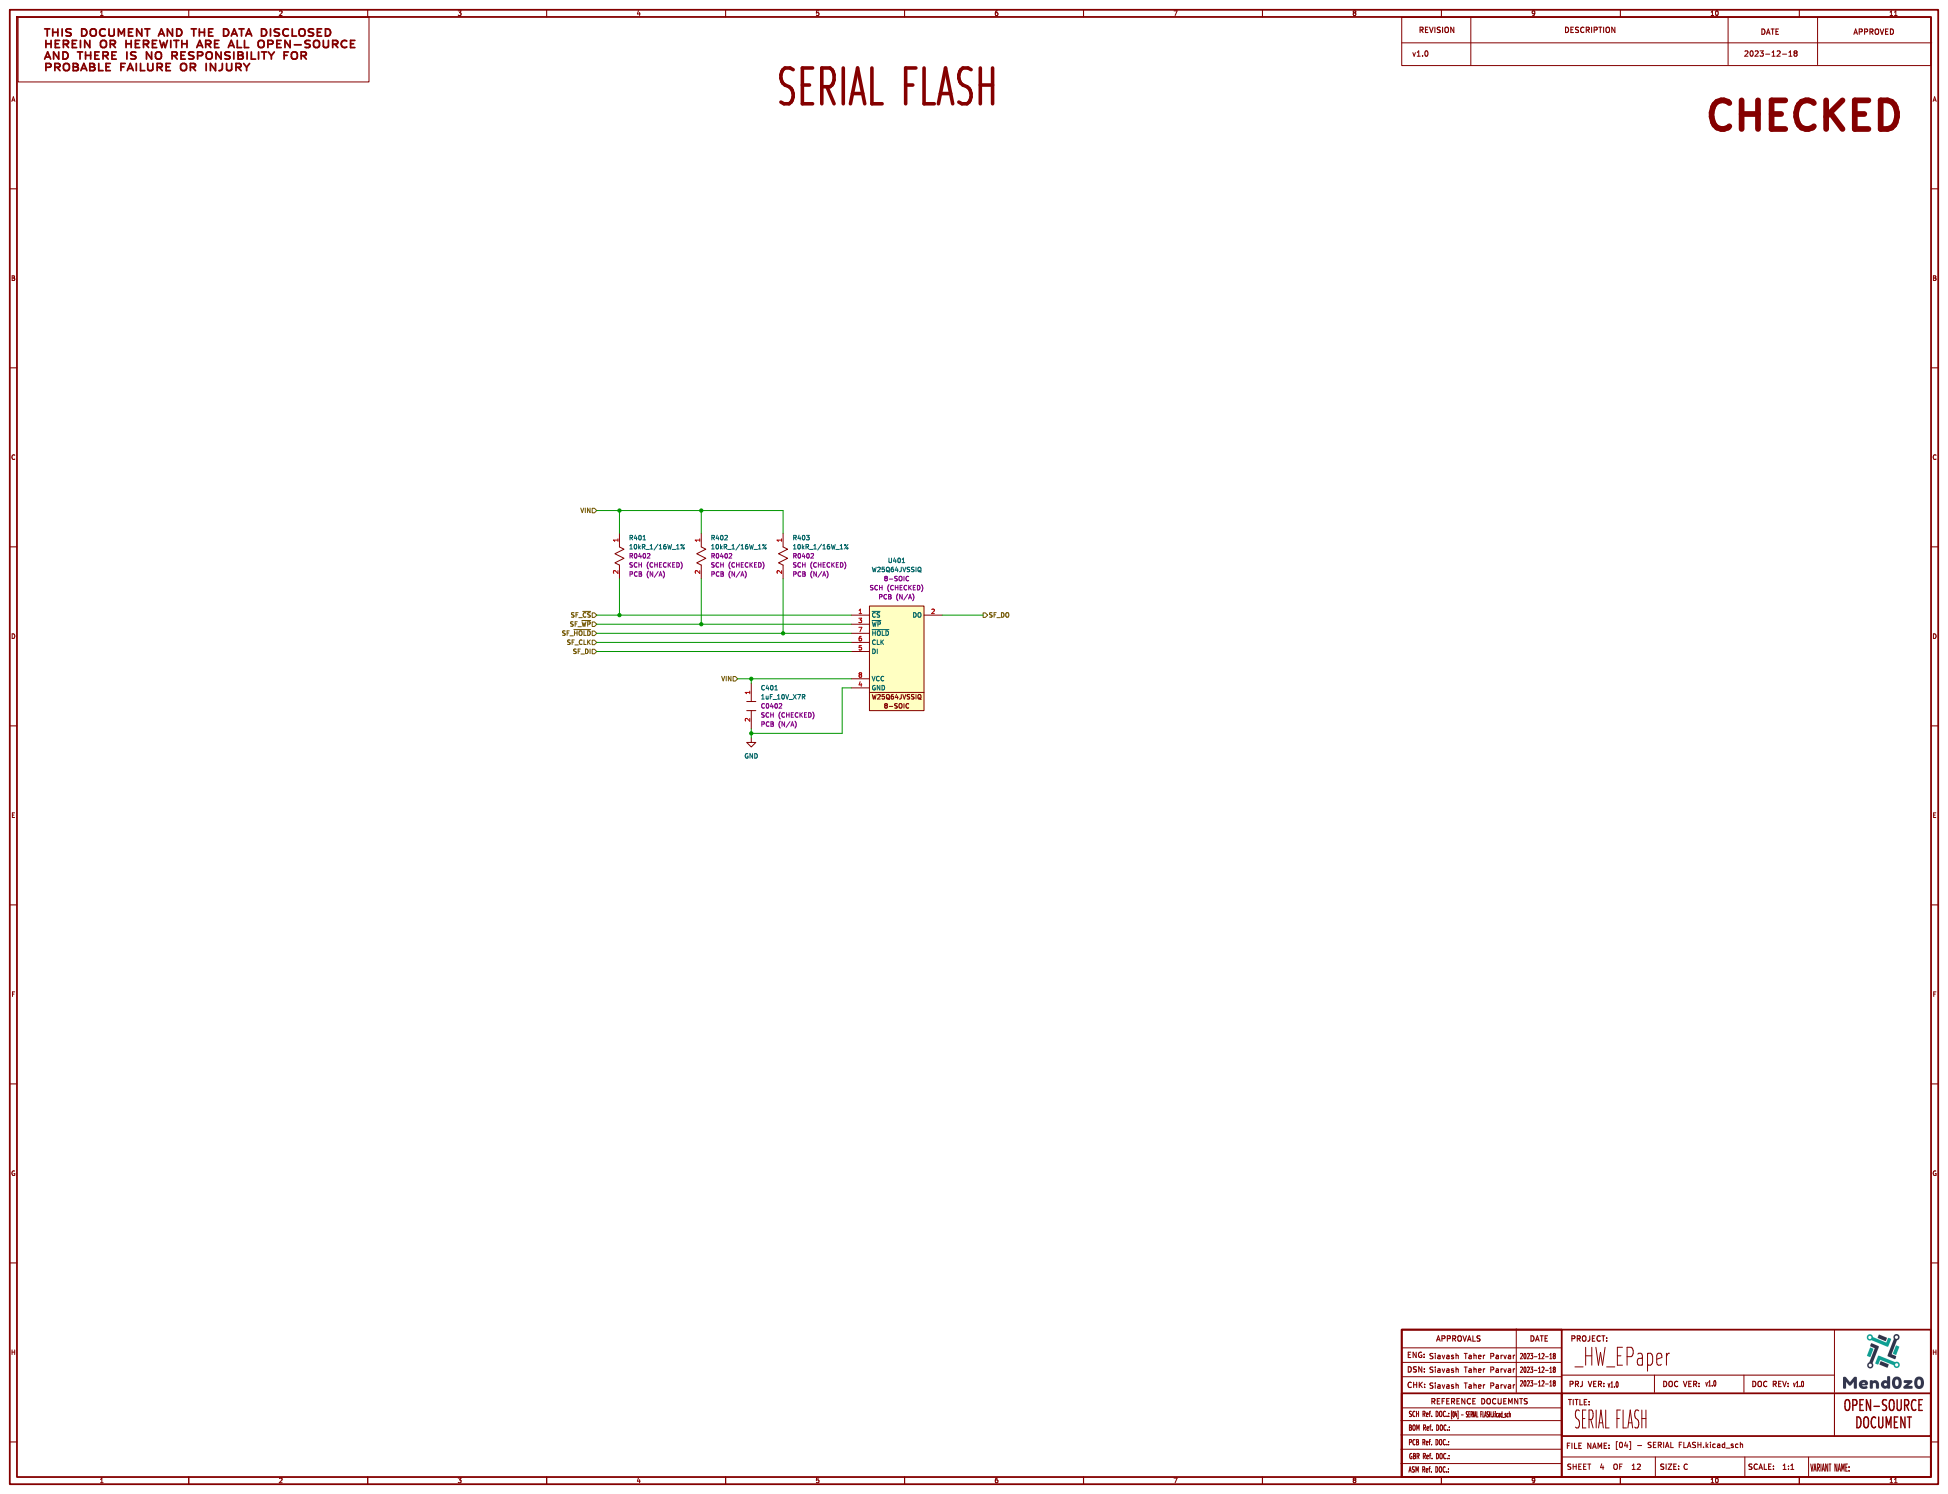
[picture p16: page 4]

R0402 SCH (CHECKED) PCB (N/A) VIN

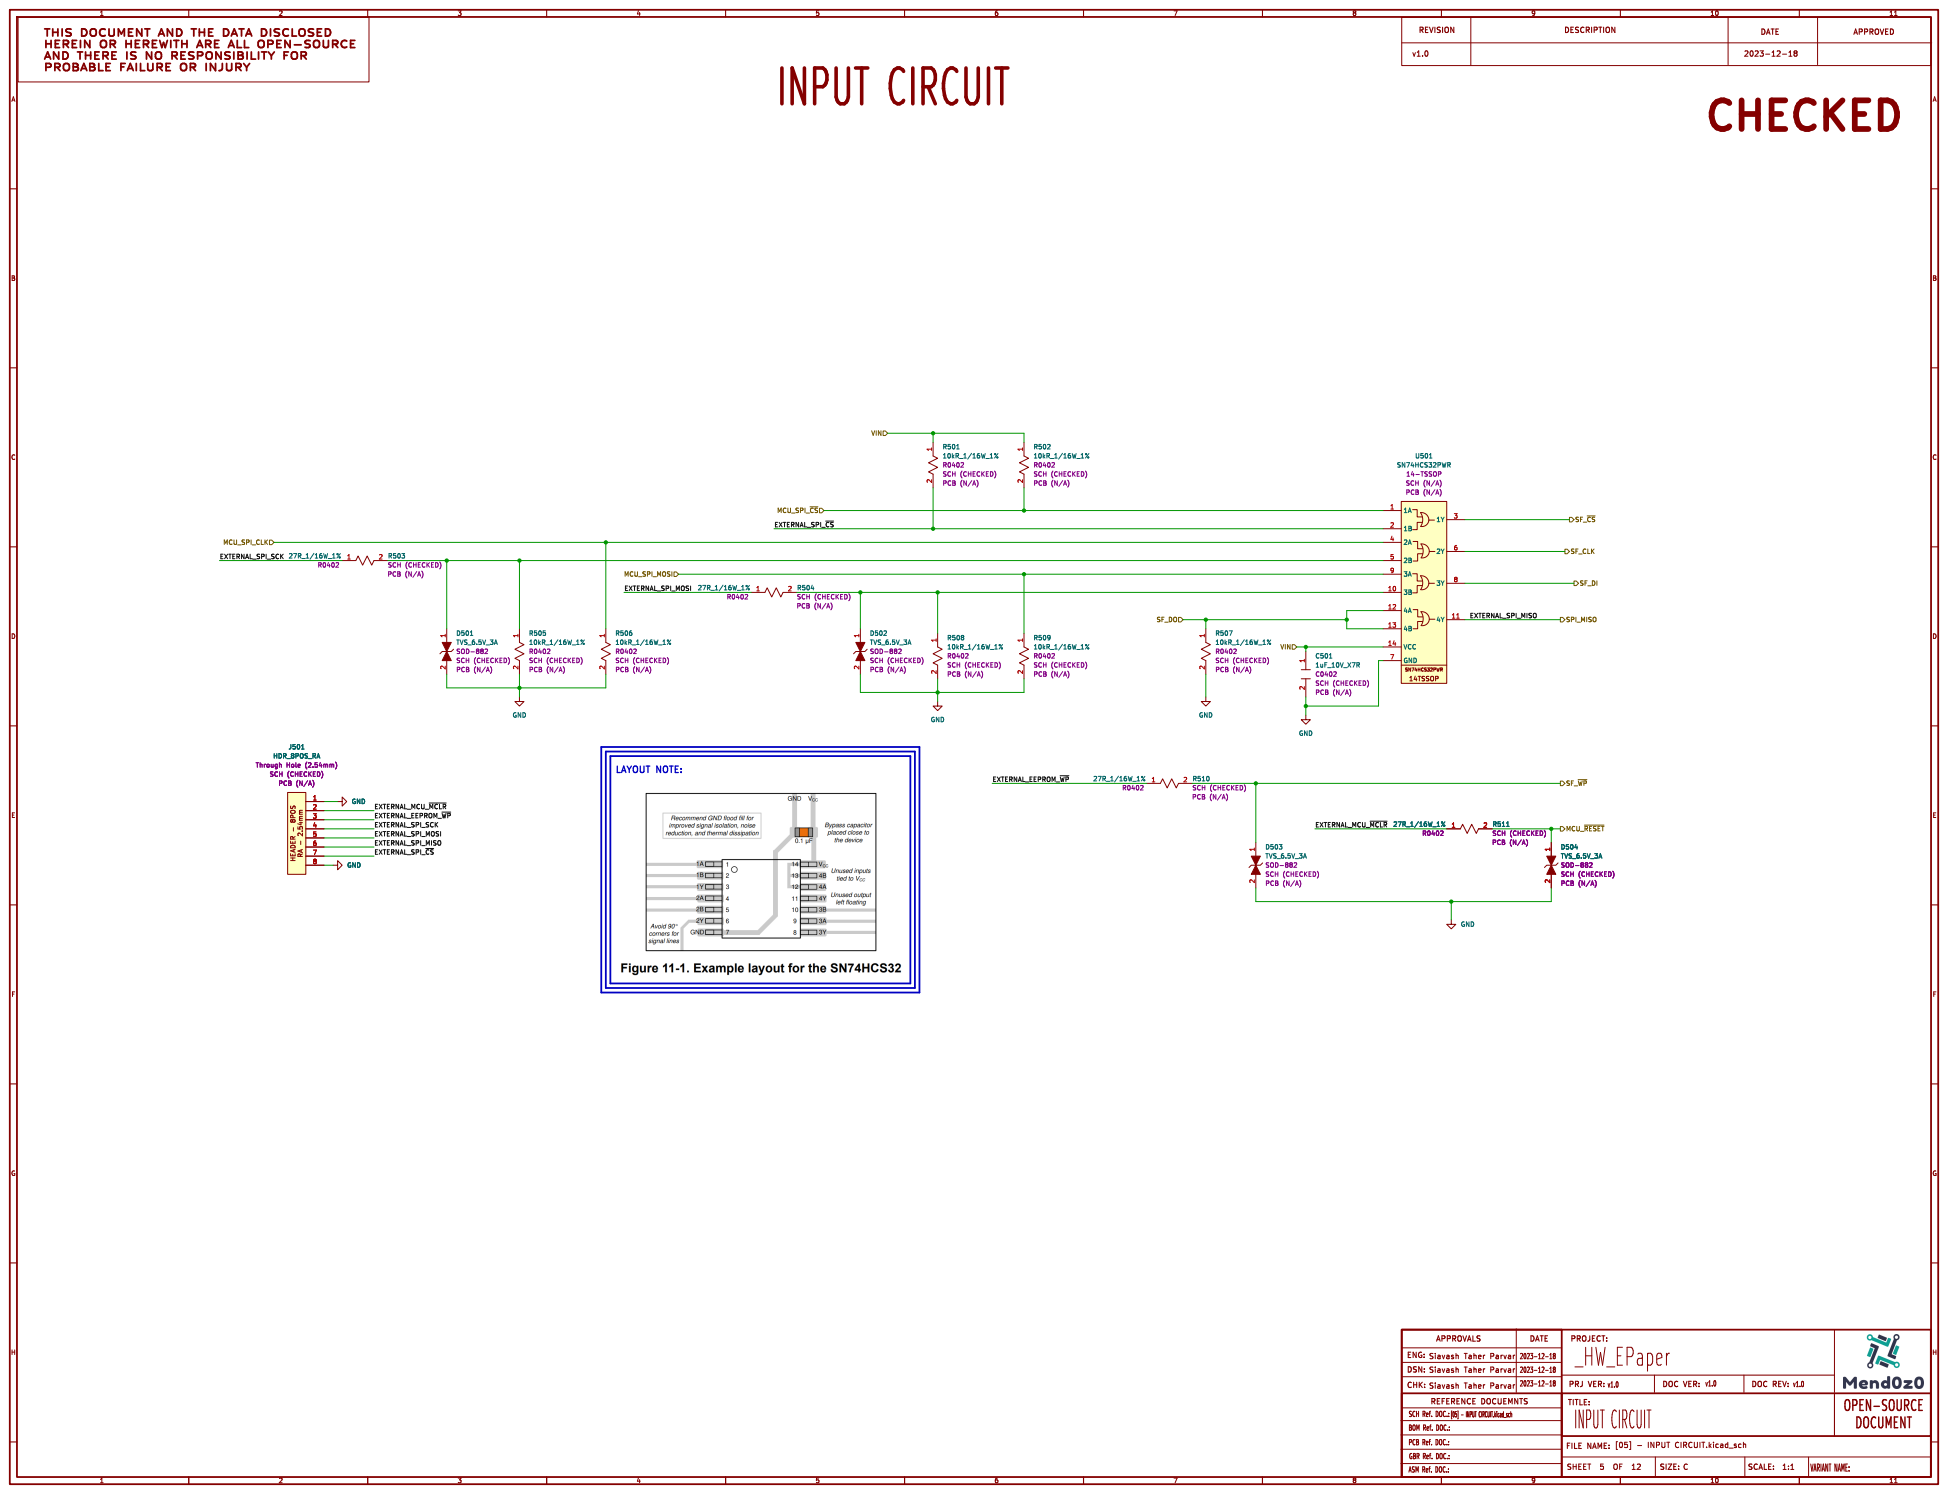
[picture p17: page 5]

R0402 SCH (CHECKED) PCB (N/A) GND GND

Through Hole (2.54mm) SCH (CHECKED) PCB (N/A) 1

SOD-882 SCH (CHECKED) PCB (N/A) 1 2

SOD-882 SCH (CHECKED) PCB (N/A) GND

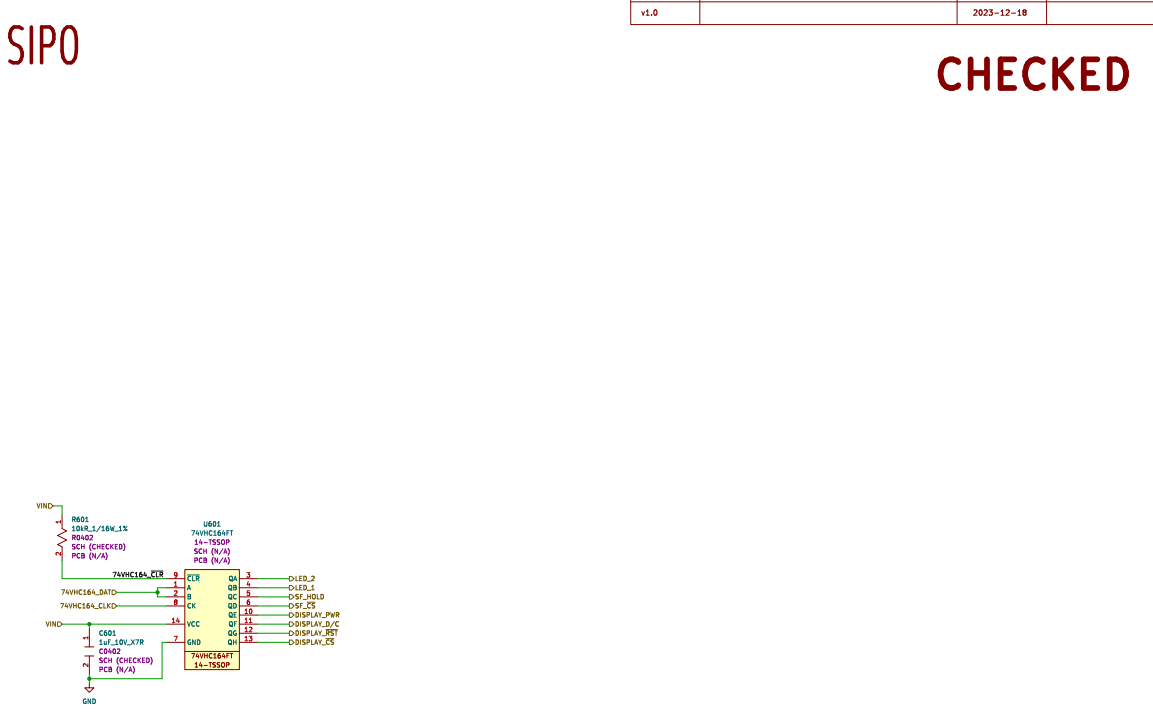
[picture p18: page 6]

C0402 SCH (CHECKED) PCB (N/A) GND

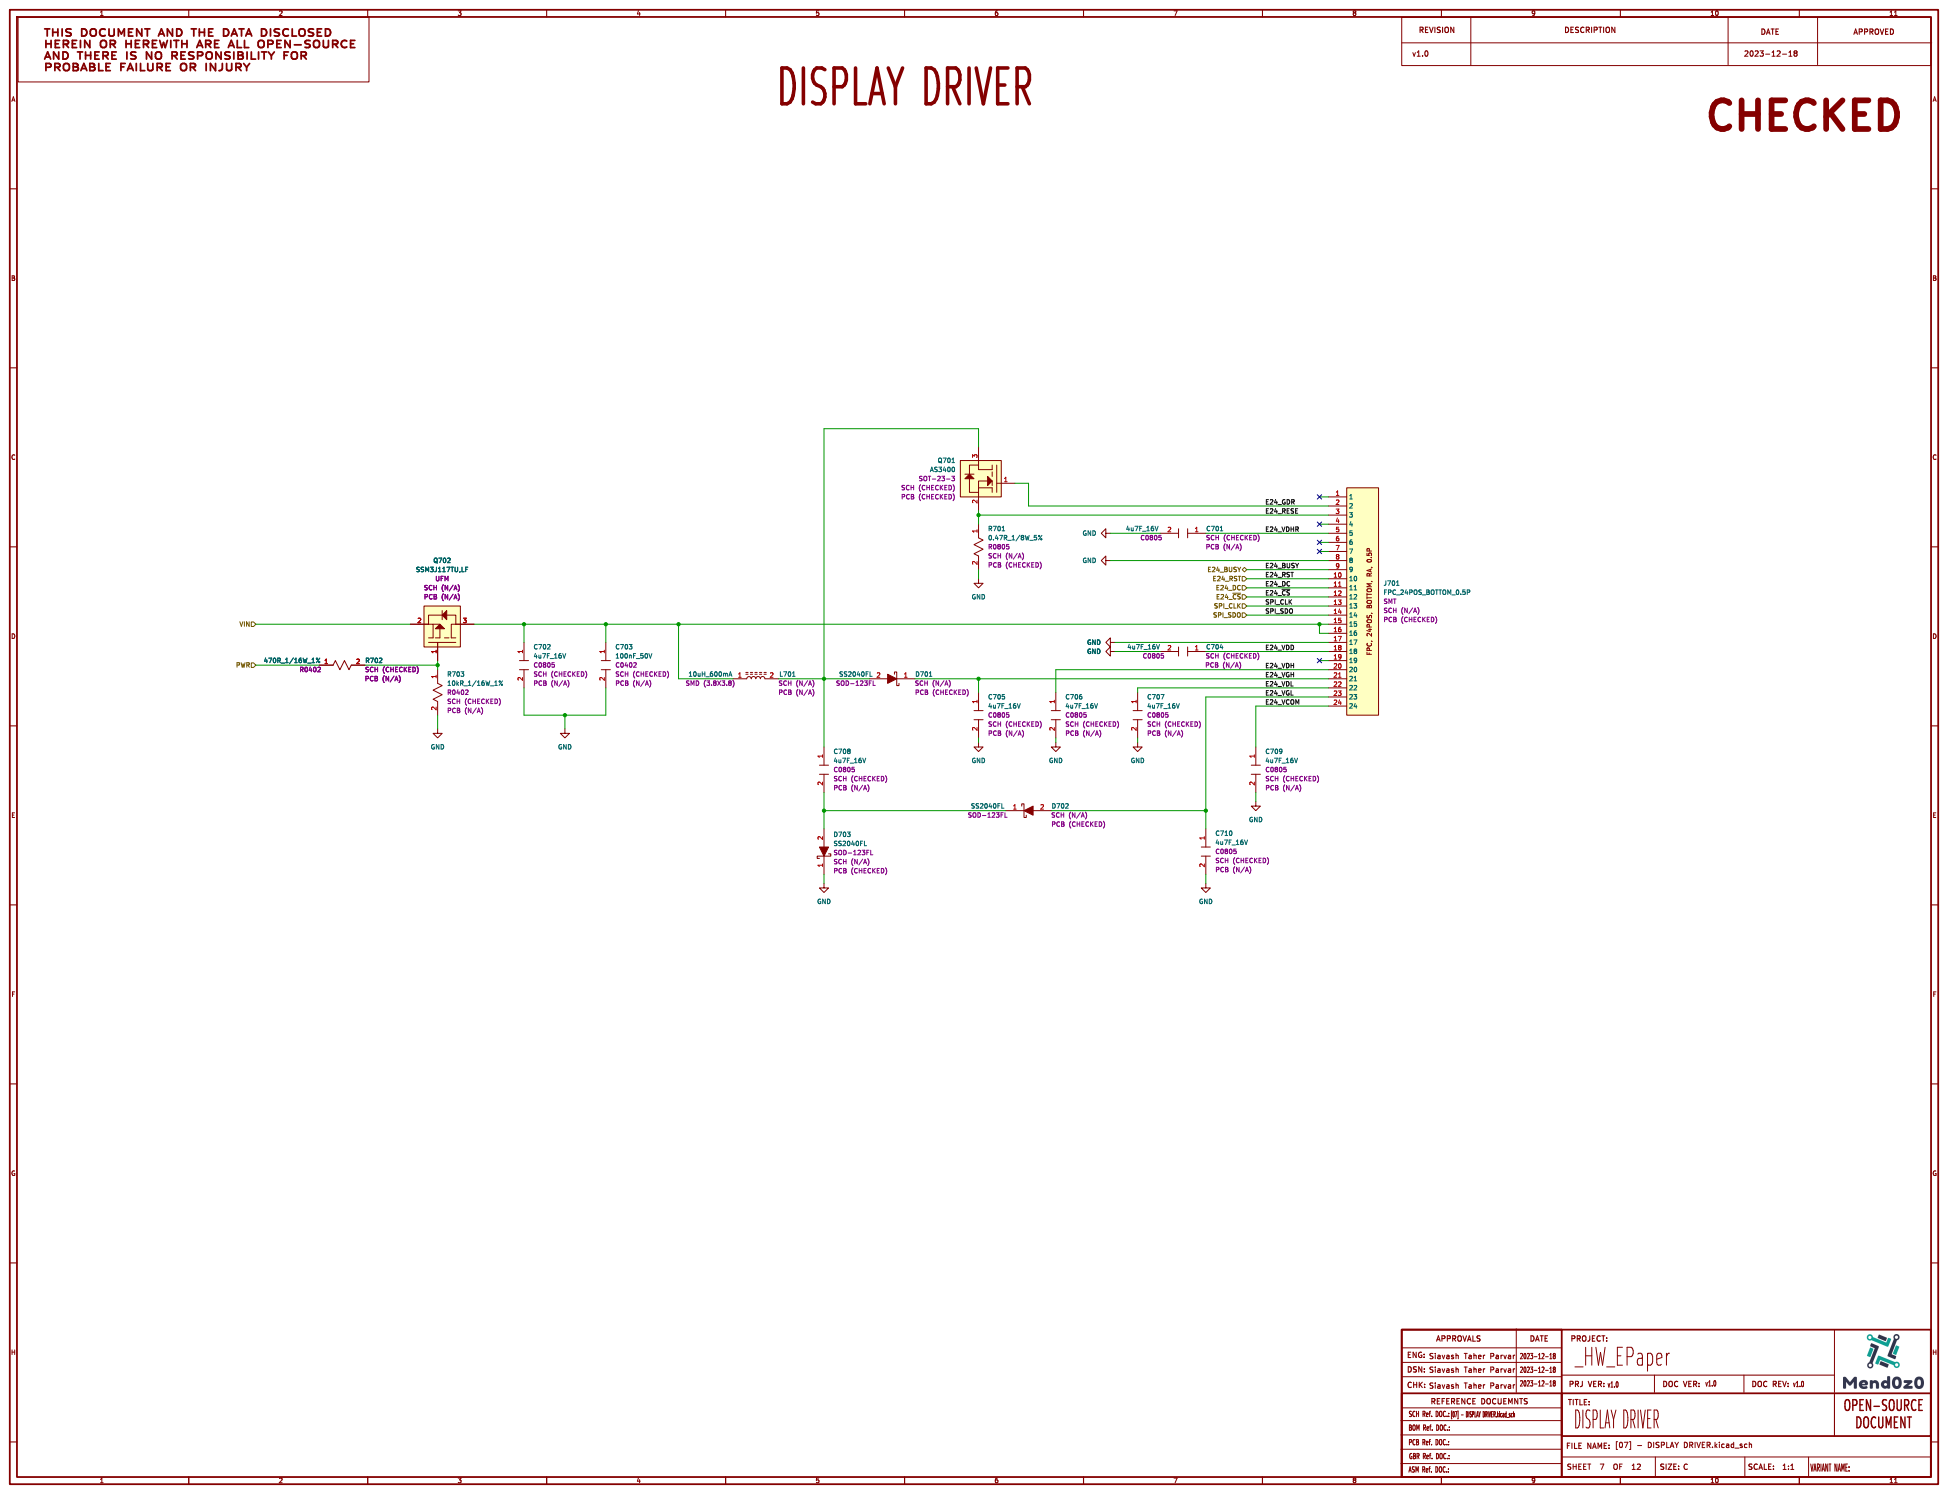
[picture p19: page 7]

2 3 Q701 AS3400 SOT-23-3 SCH (CHECKED) PCB (CHECKED) GND

E24_VGL GND GND Q702 SSM3J117TU,LF UFM
SCH (N/A) PCB (N/A) 1

100nF_50V C0402 SCH (CHECKED) PCB (N/A) GND

1 2D703 SS2040FL SOD-123FL SCH (N/A) PCB (CHECKED) 1 2 C708

4u7F_16V C0805 SCH (CHECKED) PCB (N/A) GND

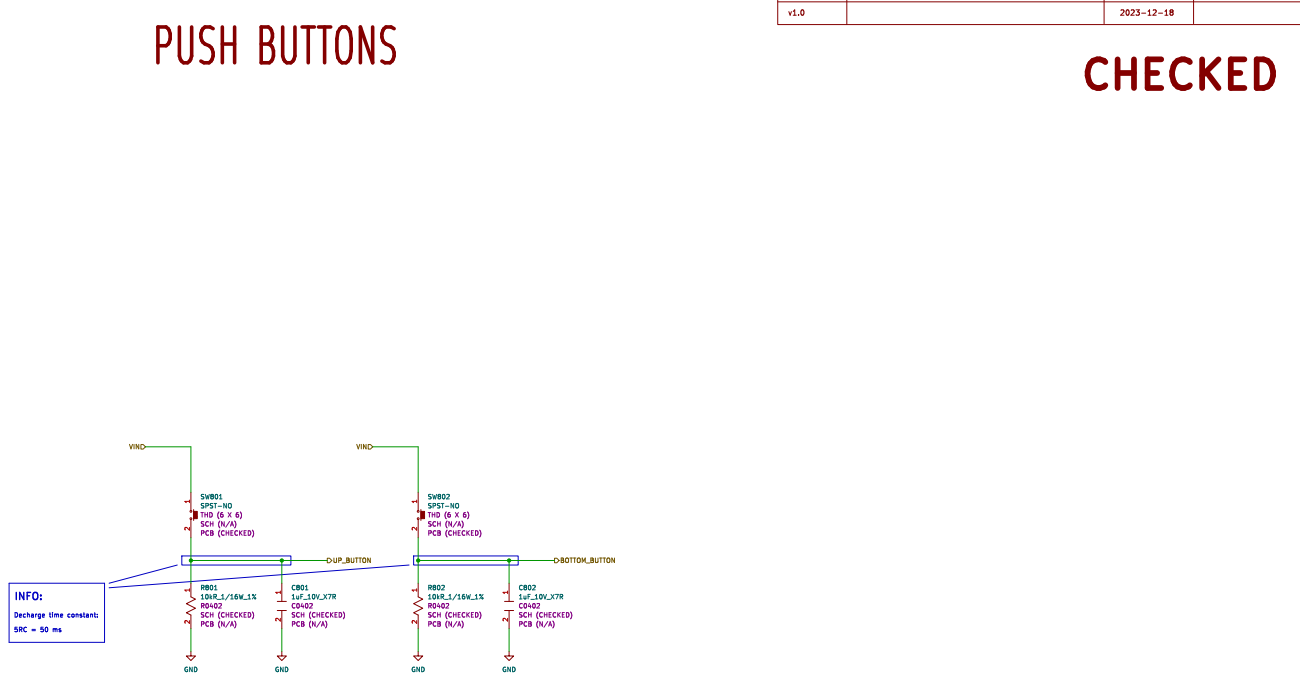
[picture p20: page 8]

C0402 SCH (CHECKED) PCB (N/A) GND

Decharge time constant: 5RC = 50 ms

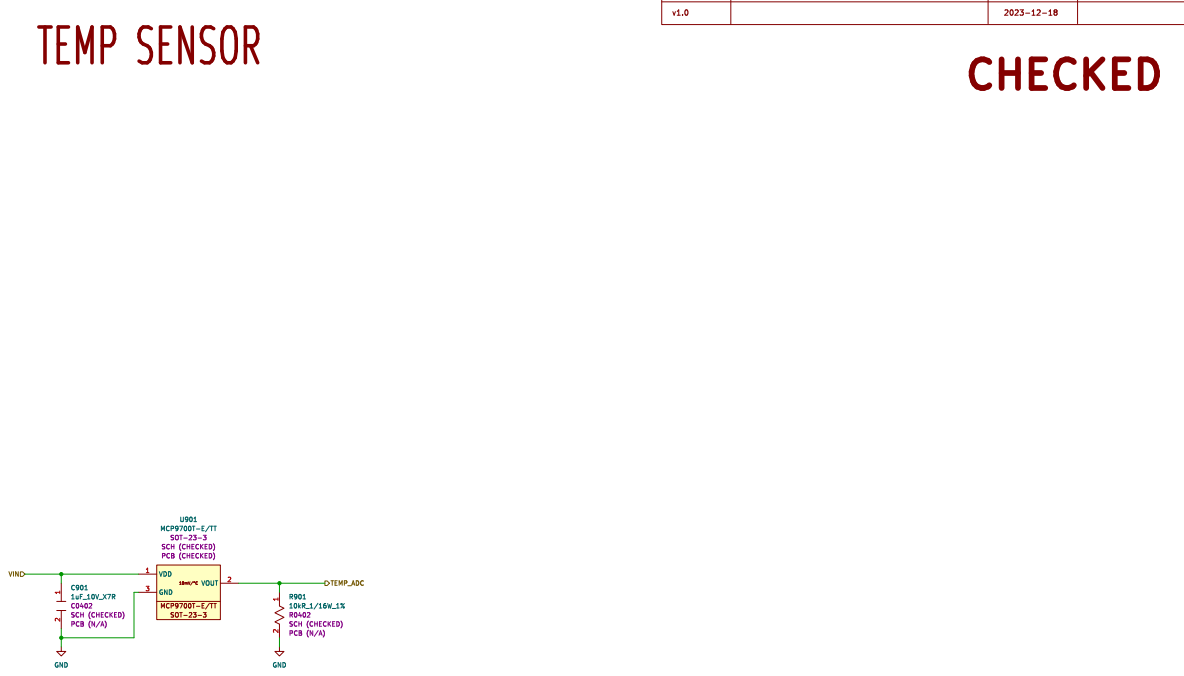
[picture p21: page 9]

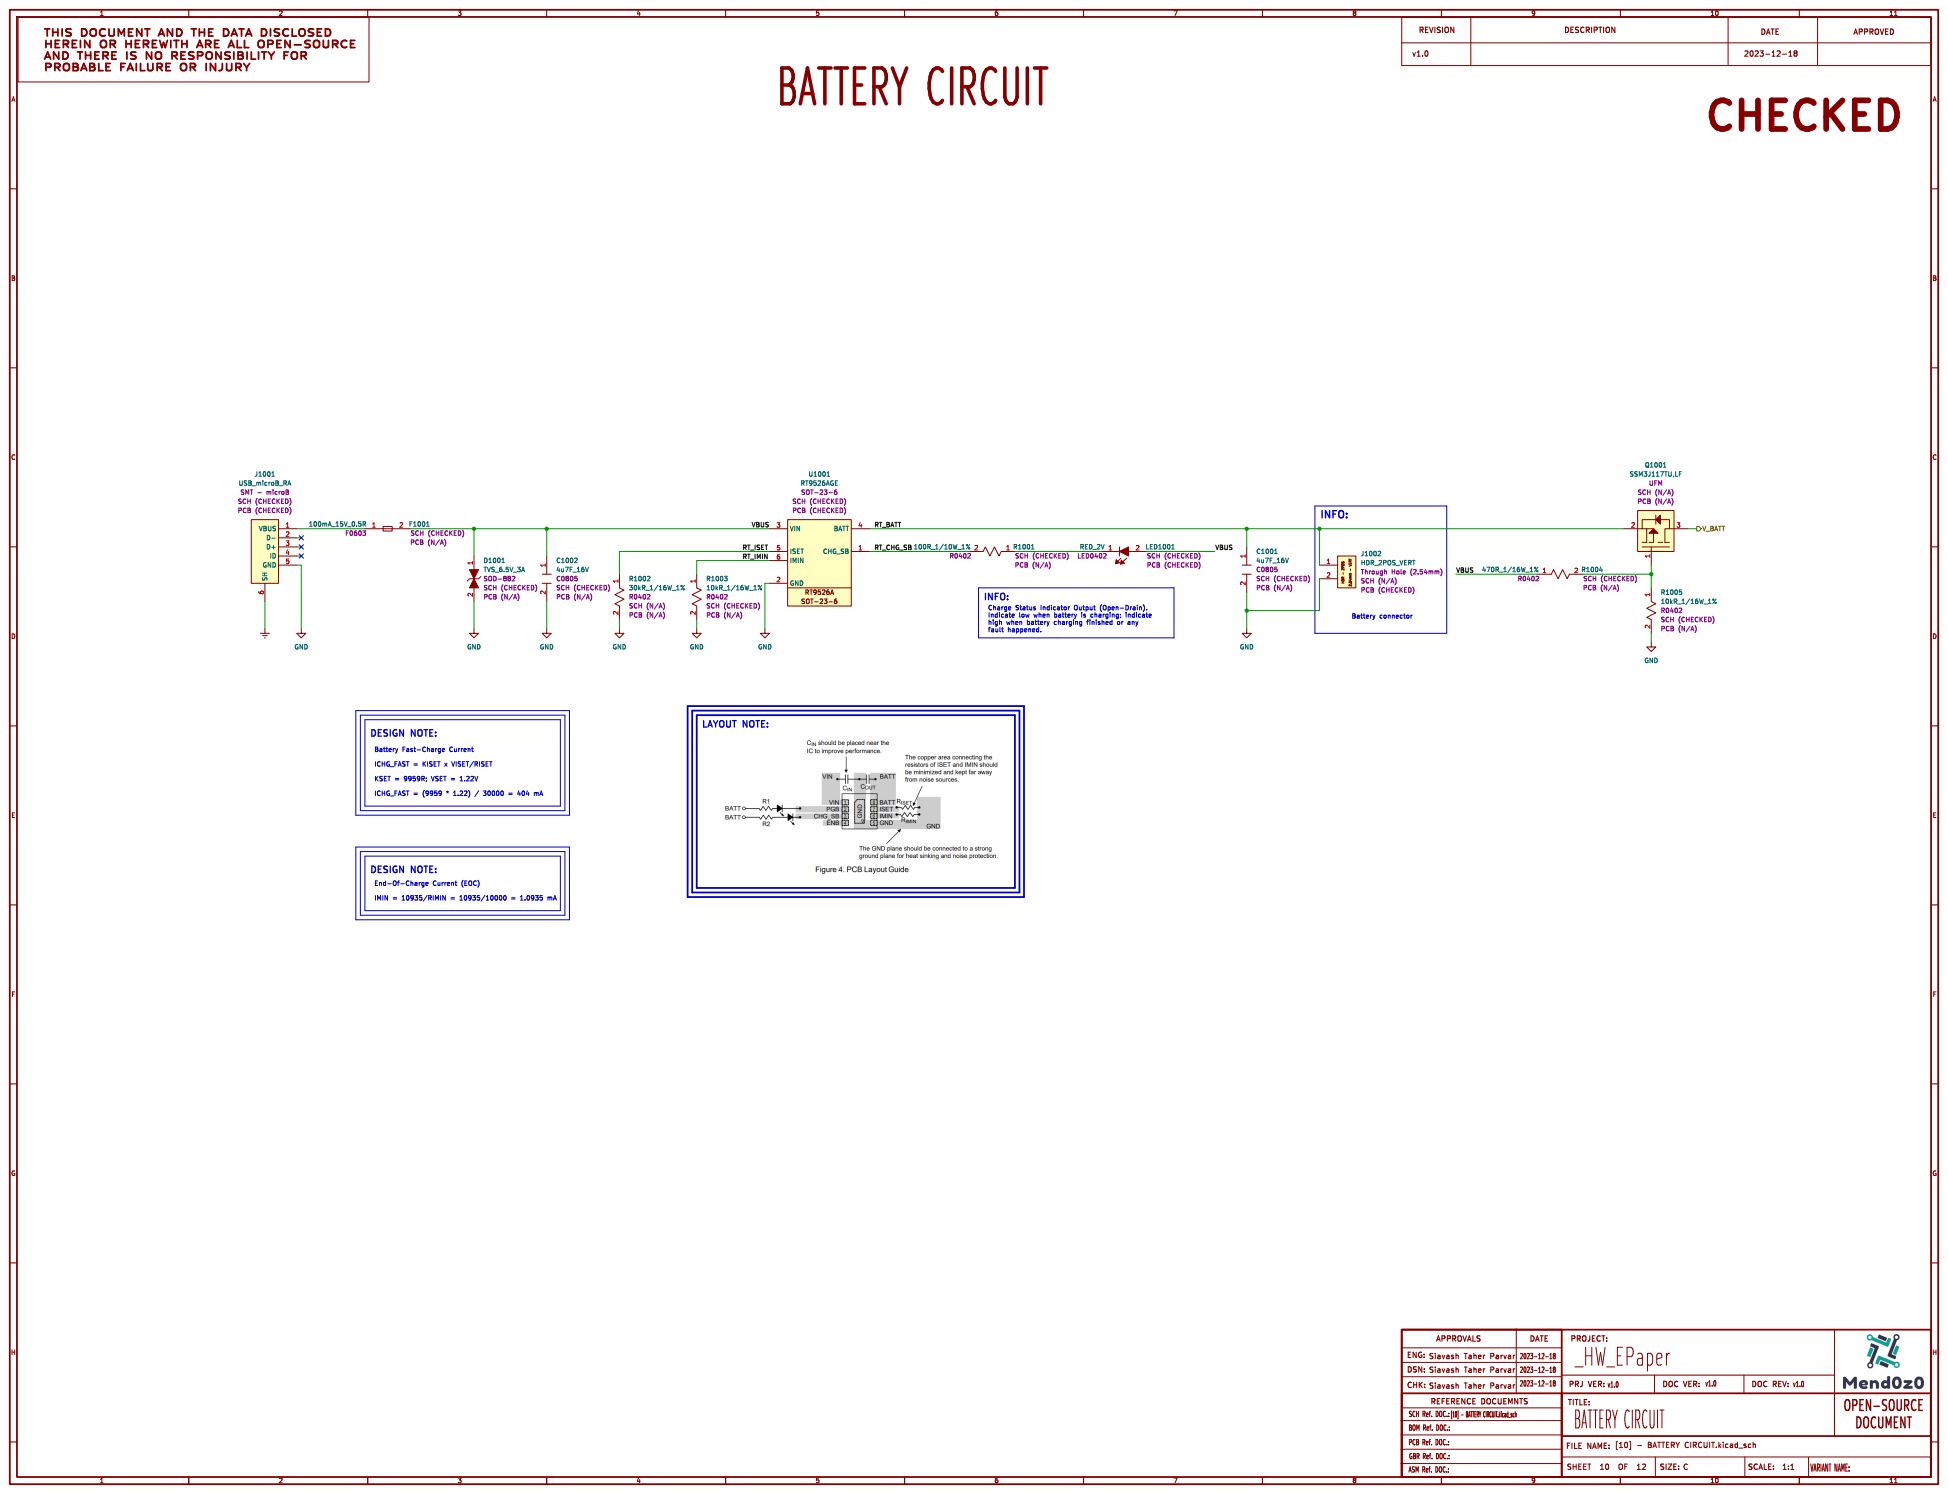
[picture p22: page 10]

J1001 USB_microB_RA
SCH (CHECKED) PCB (CHECKED) GND

SOD-882 SCH (CHECKED) PCB (N/A) GND

ICHG_FAST = KISET x VISET/RISET KSET = 9959R; VSET = 1.22V

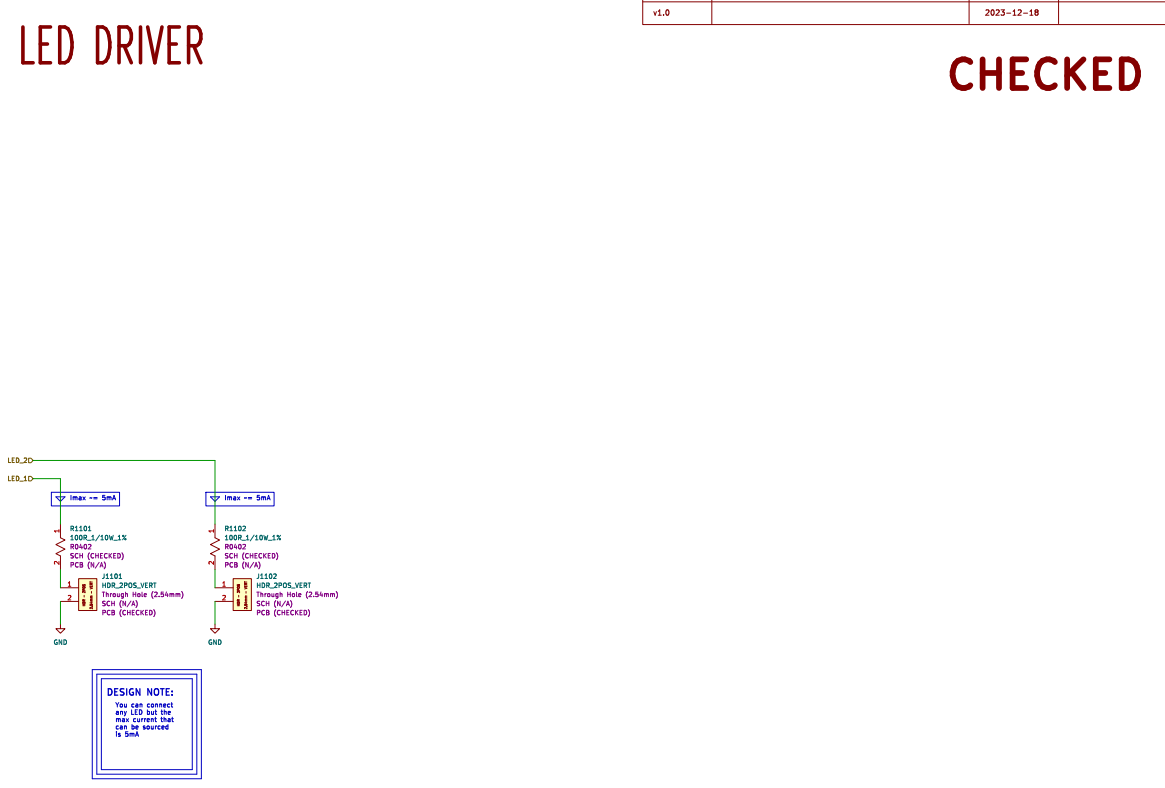
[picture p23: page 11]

R0402 SCH (CHECKED) PCB (N/A) HDR - 2POS

You can connect any LED but the max current that can be sourced

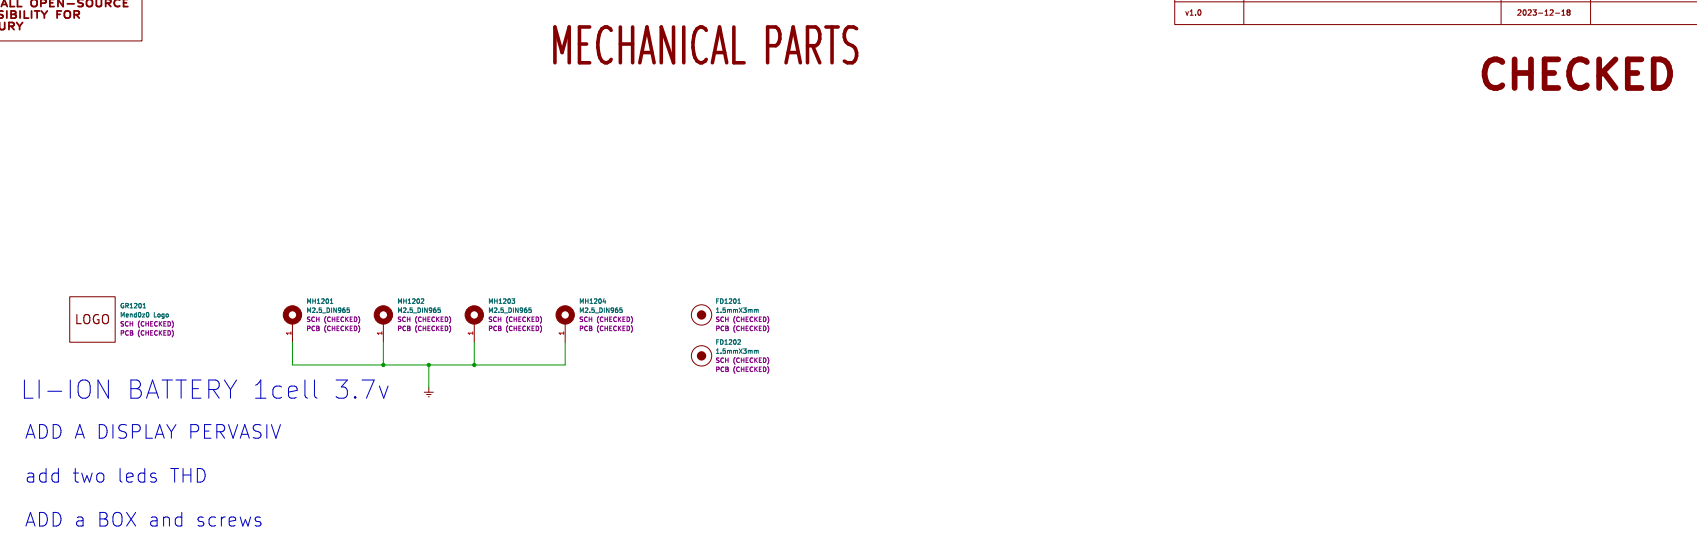
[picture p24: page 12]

1 MH1202 M2.5_DIN965 SCH (CHECKED) PCB (CHECKED)

1.5mmX3mm
SCH (CHECKED) PCB (CHECKED)

add two leds THD

ADD a BOX and screws

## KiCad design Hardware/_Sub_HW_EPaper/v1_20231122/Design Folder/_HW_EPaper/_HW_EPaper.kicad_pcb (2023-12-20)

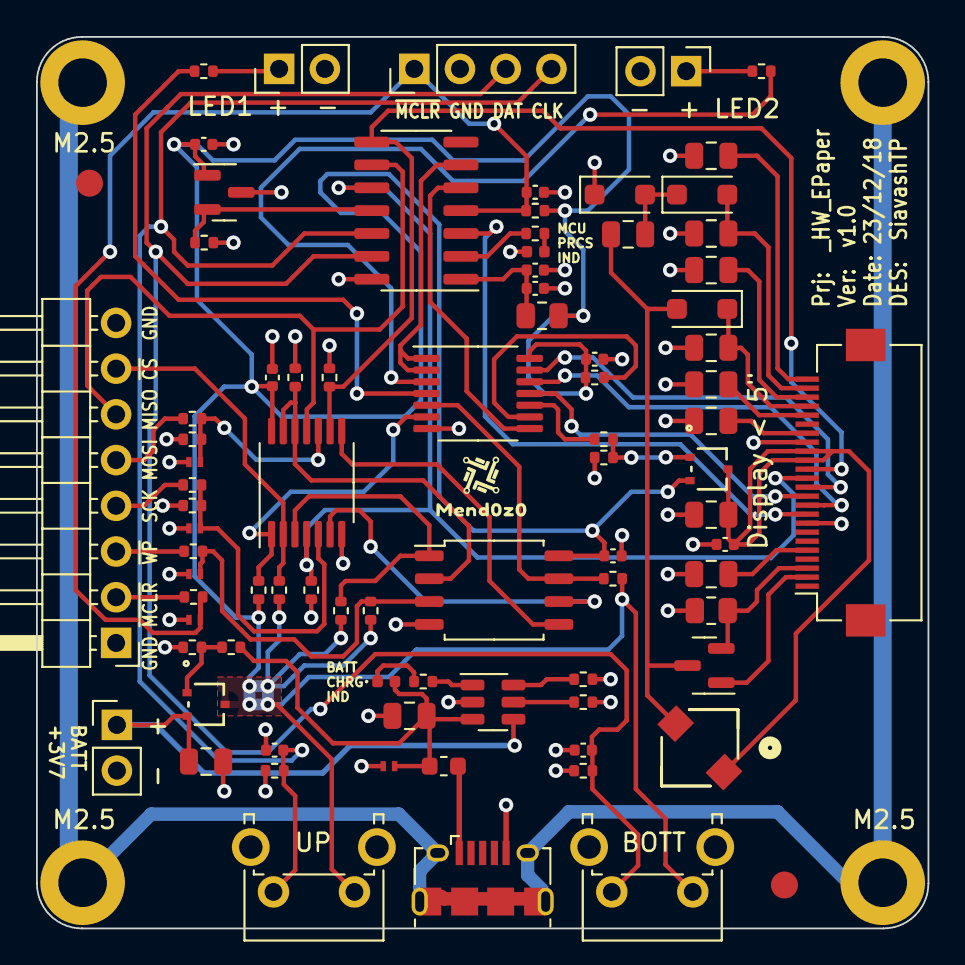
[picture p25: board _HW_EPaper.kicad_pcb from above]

Board: 2 copper layers, 49.5 x 49.5 mm, 89 parts (0 on the bottom side), 60 nets.

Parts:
C301, C303, C703: 100nF_50V; C_0402_1005Metric
C302, C401, C501, C601, C801, C802, C901: 1uF_10V_X7R; C_0402_1005Metric
C701, C702, C704, C705, C706, C707, C708, C709, C710, C1001, C1002: 4u7F_16V; C_0805_2012Metric
D501, D502, D503, D504, D1001: TVS_6.5V_3A; CR_7PCT_L3F_TOS
D701, D702, D703: SS2040FL; D_SOD-123F
F1001: 100mA_15V_0.5R; Fuse_0603_1608Metric
FD1201, FD1202: 1.5mmX3mm; Fiducial_1.5mm_Mask3mm
GR1201: Mend0z0 Logo; LOGO_MEND0Z0
J301: HDR_4POS_VERT; PinHeader_1x04_P2.54mm_Vertical
J501: HDR_8POS_RA; PinHeader_1x08_P2.54mm_Horizontal
J701: FPC_24POS_BOTTOM_0.5P; Hirose_FH12-24S-0.5SH_1x24-1MP_P0.50mm_Horizontal
J1001: USB_microB_RA; USB_Micro-B_Amphenol_10118194_Horizontal
J1002, J1101, J1102: HDR_2POS_VERT; PinHeader_1x02_P2.54mm_Vertical
L701: 10uH_600mA; IND_CDRH3D11HPNP-100NC_SUM
LED301, LED1001: RED_2V; LED_0402_1005Metric
MH1201, MH1202, MH1203, MH1204: M2.5_DIN965; MountingHole_2.7mm_M2.5_DIN965_Pad
Q701: AS3400; SOT-23
Q702, Q1001: SSM3J117TU,LF; UFM_TOS
R301, R401, R402, R403, R501, R502, R505, R506, R507, R508, R509, R601, R703, R801, R802, R901, R1003, R1005: 10kR_1/16W_1%; R_0402_1005Metric
R302, R702, R1004: 470R_1/16W_1%; R_0402_1005Metric
R303: 1R_1/4W_1%; R_0805_2012Metric
R503, R504, R510, R511: 27R_1/16W_1%; R_0402_1005Metric
R701: 0.47R_1/8W_5%; R_0805_2012Metric
R1001, R1101, R1102: 100R_1/10W_1%; R_0402_1005Metric
R1002: 30kR_1/16W_1%; R_0402_1005Metric
SW801, SW802: SPST-NO; SW_Tactile_SPST_Angled_PTS645Vx31-2LFS
U301: PIC16F15223_8BIT; SO-14_3.9x8.65mm_P1.27mm
U401: W25Q64JVSSIQ; SOIC-8_5.275x5.275mm_P1.27mm
U501: SN74HCS32PWR; TSSOP-14_4.4x5mm_P0.65mm
U601: 74VHC164FT; TSSOP-14_4.4x5mm_P0.65mm
U901: MCP9700T-E/TT; SOT-23
U1001: RT9526AGE; SOT-23-6

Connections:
/BLOCK DIAGRAM/BATTERY CHARGER/RT_BATT: C1001.1, J1002.1, Q1001.2, U1001.4 (BATT)
/BLOCK DIAGRAM/BATTERY CHARGER/RT_CHG_SB: R1001.2, U1001.1 (CHG_SB)
/BLOCK DIAGRAM/BATTERY CHARGER/RT_IMIN: R1003.1, U1001.6 (IMIN)
/BLOCK DIAGRAM/BATTERY CHARGER/RT_ISET: R1002.1, U1001.5 (ISET)
/BLOCK DIAGRAM/BATTERY CHARGER/VBUS: C1002.1, D1001.1, F1001.2, LED1001.2, R1004.1, U1001.3 (VIN)
/BLOCK DIAGRAM/BATTERY CHARGER/V_BATT: C401.1, C501.1, C601.1, C901.1, Q702.2, Q1001.3, R301.1, R303.1, R401.1, R402.1, R403.1, R501.1, R502.1, R601.1, SW801.1, SW802.1, U401.8 (VCC), U501.14 (VCC), U601.14 (VCC), U901.1 (VDD)
/BLOCK DIAGRAM/DISPLAY DRIVER/E24_BUSY: J701.9, U301.3 (RA4)
/BLOCK DIAGRAM/DISPLAY DRIVER/E24_DC: J701.11, U601.11 (QF)
/BLOCK DIAGRAM/DISPLAY DRIVER/E24_GDR: J701.2, Q701.1
/BLOCK DIAGRAM/DISPLAY DRIVER/E24_RESE: J701.3, Q701.2, R701.1
/BLOCK DIAGRAM/DISPLAY DRIVER/E24_RST: J701.10, U601.12 (QG)
/BLOCK DIAGRAM/DISPLAY DRIVER/E24_VCOM: C709.1, J701.24
/BLOCK DIAGRAM/DISPLAY DRIVER/E24_VDD: C704.1, J701.18
/BLOCK DIAGRAM/DISPLAY DRIVER/E24_VDH: C706.1, J701.20
/BLOCK DIAGRAM/DISPLAY DRIVER/E24_VDHR: C701.1, J701.5
/BLOCK DIAGRAM/DISPLAY DRIVER/E24_VDL: C707.1, J701.22
/BLOCK DIAGRAM/DISPLAY DRIVER/E24_VGH: C705.1, D701.1, J701.21
/BLOCK DIAGRAM/DISPLAY DRIVER/E24_VGL: C710.1, D702.2, J701.23
/BLOCK DIAGRAM/DISPLAY DRIVER/E24_~CS: J701.12, U601.13 (QH)
/BLOCK DIAGRAM/DISPLAY DRIVER/PWR: R702.1, U601.10 (QE)
/BLOCK DIAGRAM/DISPLAY DRIVER/SPI_CLK: J701.13, R506.1, U301.10 (RC0), U501.4 (2A)
/BLOCK DIAGRAM/DISPLAY DRIVER/SPI_SDO: J701.14, R509.1, U301.8 (RC2), U501.9 (3A)
/BLOCK DIAGRAM/INPUT CIRCUIT/EXTERNAL_EEPROM_~WP: J501.3, R510.1
/BLOCK DIAGRAM/INPUT CIRCUIT/EXTERNAL_MCU_~MCLR: J501.2, R511.1
/BLOCK DIAGRAM/INPUT CIRCUIT/EXTERNAL_SPI_MISO: J501.6, U301.9 (RC1), U501.11 (4Y)
/BLOCK DIAGRAM/INPUT CIRCUIT/EXTERNAL_SPI_MOSI: J501.5, R504.1
/BLOCK DIAGRAM/INPUT CIRCUIT/EXTERNAL_SPI_SCK: J501.4, R503.1
/BLOCK DIAGRAM/INPUT CIRCUIT/EXTERNAL_SPI_~CS: J501.7, R501.2, U501.2 (1B)
/BLOCK DIAGRAM/INPUT CIRCUIT/MCU_SPI_~CS: R502.2, U501.1 (1A), U601.6 (QD)
/BLOCK DIAGRAM/INPUT CIRCUIT/SF_CLK: U401.6 (CLK), U501.6 (2Y)
/BLOCK DIAGRAM/INPUT CIRCUIT/SF_DI: U401.5 (DI), U501.8 (3Y)
/BLOCK DIAGRAM/INPUT CIRCUIT/SF_DO: R507.1, U401.2 (DO), U501.12 (4A), U501.13 (4B)
/BLOCK DIAGRAM/INPUT CIRCUIT/SF_~CS: R401.2, U401.1 (~CS), U501.3 (1Y)
/BLOCK DIAGRAM/INPUT CIRCUIT/SF_~WP: D503.1, R402.2, R510.2, U401.3 (~WP)
/BLOCK DIAGRAM/LED DRIVER/LED_1: R1101.1, U601.4 (QB)
/BLOCK DIAGRAM/LED DRIVER/LED_2: R1102.1, U601.3 (QA)
/BLOCK DIAGRAM/MICROCONTROLLER/IND_LED: R302.1, U301.2 (RA5)
/BLOCK DIAGRAM/MICROCONTROLLER/PIC_ICSPCLK: C802.1, J301.4, R802.1, SW802.2, U301.12 (ICSPCLK/RA1)
/BLOCK DIAGRAM/MICROCONTROLLER/PIC_ICSPDAT: C801.1, J301.3, R801.1, SW801.2, U301.13 (ICSPDAT/RA0)
/BLOCK DIAGRAM/MICROCONTROLLER/PIC_~MCLR: C301.1, D504.1, J301.1, R301.2, R511.2, U301.4 (~MCLR/RA3)
/BLOCK DIAGRAM/MICROCONTROLLER/SIPO_CLK: U301.5 (RC5), U601.8 (CK)
/BLOCK DIAGRAM/MICROCONTROLLER/SIPO_DATA: U301.6 (RC4), U601.1 (A), U601.2 (B)
/BLOCK DIAGRAM/MICROCONTROLLER/TEMP_ADC: R901.1, U301.11 (RA2), U901.2 (VOUT)
/BLOCK DIAGRAM/SERIAL FLASH/SF_~HOLD: R403.2, U401.7 (~HOLD), U601.5 (QC)
/BLOCK DIAGRAM/SHIFT REGISTER (SIPO)/74VHC164_~CLR: R601.2, U601.9 (~CLR)
Earth: J1001.6 (SH), MH1201.1, MH1202.1, MH1203.1, MH1204.1
GND: C301.2, C302.2, C303.2, C401.2, C501.2, C601.2, C701.2, C702.2, C703.2, C704.2, C705.2, C706.2, C707.2, C709.2, C710.2, C801.2, C802.2, C901.2, C1001.2, C1002.2, D501.2, D502.2, D503.2, D504.2, D703.1, D1001.2, J301.2, J501.1, J501.8, J701.8, J701.17, J1001.5 (GND), J1002.2, J1101.2, J1102.2, LED301.1, R505.2, R506.2, R507.2, R508.2, R509.2, R701.2, R703.2, R801.2, R802.2, R901.2, R1002.2, R1003.2, R1005.2, U301.14 (VSS), U401.4 (GND), U501.7 (GND), U601.7 (GND), U901.3 (GND), U1001.2 (GND)
unnamed: C702.1, C703.1, J701.15, J701.16, L701.1, Q702.3
unnamed: C708.1, D701.2, L701.2, Q701.3
unnamed: C708.2, D702.1, D703.2
unnamed: F1001.1, J1001.1 (VBUS)
unnamed: J1101.1, R1101.2
unnamed: J1102.1, R1102.2
unnamed: LED301.2, R302.2
unnamed: LED1001.1, R1001.1
unnamed: Q702.1, R702.2, R703.1
unnamed: Q1001.1, R1004.2, R1005.1
unnamed: C302.1, C303.1, R303.2, U301.1 (VDD)
unnamed: D501.1, R503.2, R505.1, U501.5 (2B)
unnamed: D502.1, R504.2, R508.1, U501.10 (3B)

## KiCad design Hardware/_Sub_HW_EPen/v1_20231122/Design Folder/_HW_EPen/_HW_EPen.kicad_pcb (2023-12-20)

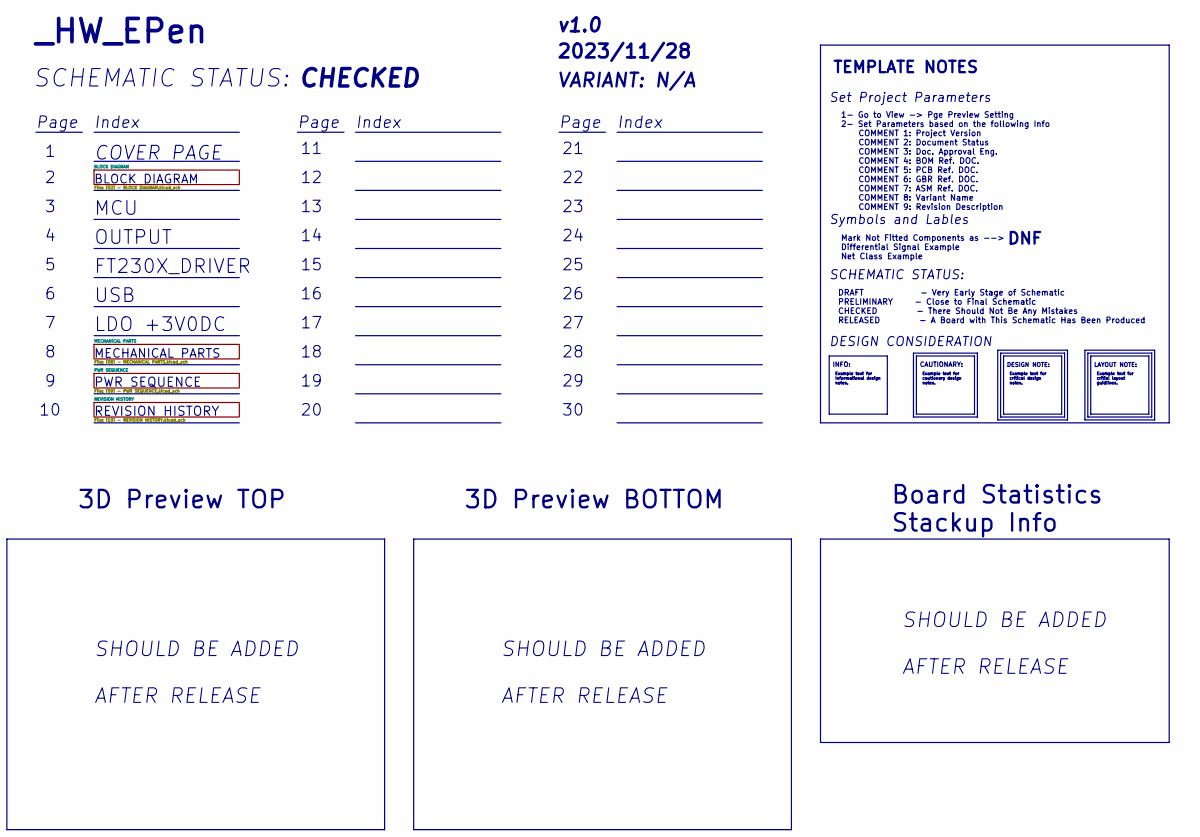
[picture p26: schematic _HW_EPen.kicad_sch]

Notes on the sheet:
Set Project Parameters
SHOULD BE ADDED AFTER RELEASE
MECHANICAL PARTS
Index
SCHEMATIC STATUS:
SCHEMATIC STATUS:
Page
DESIGN CONSIDERATION
USB
Example text for Informational design notes.
${COMMENT2}
${REVISION}
VARIANT: ${COMMENT8}
1- Go to View -> Pge Preview Setting 2- Set Parameters based on the following Info COMMENT 1: Project Version COMMENT 2: Document Status COMMENT 3: Doc. Approval Eng. COMMENT 4: BOM Ref. DOC. COMMENT 5: PCB Ref. DOC. COMMENT 6: GBR Ref. DOC. COMMENT 7: ASM Ref. DOC. COMMENT 8: Variant Name COMMENT 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
COVER PAGE
OUTPUT
Mark Not Fitted Components as --> Differential Signal Example Net Class Example
Board Statistics Stackup Info
TEMPLATE NOTES
${ISSUE_DATE}
Example text for critial layout guidlines.
MCU
INFO:
${TITLE}
DESIGN NOTE:
Example text for critical design notes.
3D Preview TOP
PWR SEQUENCE
3D Preview BOTTOM
Example text for cautionary design notes.
CAUTIONARY:
Symbols and Lables
DNF
LDO +3V0DC
REVISION HISTORY
FT230X_DRIVER
BLOCK DIAGRAM
LAYOUT NOTE:
DRAFT - Very Early Stage of Schematic PRELIMINARY - Close to Final Schematic CHECKED - There Should Not Be Any Mistakes RELEASED - A Board with This Schematic Has Been Produced

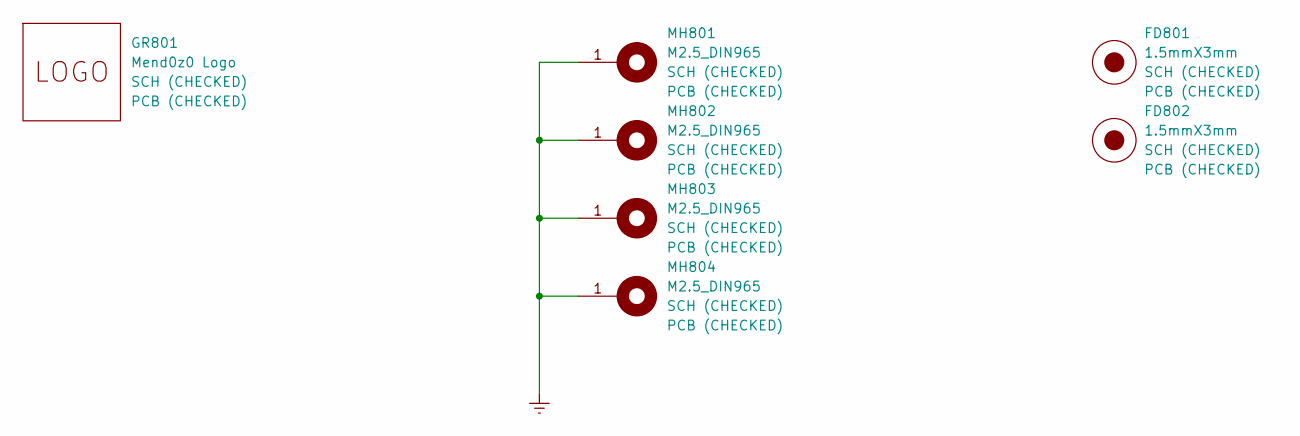
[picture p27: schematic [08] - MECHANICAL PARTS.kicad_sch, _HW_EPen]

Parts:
FD801, FD802: 1.5mmX3mm; Fiducial_1.5mm_Mask3mm
GR801: Mend0z0 Logo; LOGO_MEND0Z0
MH801, MH802, MH803, MH804: M2.5_DIN965; MountingHole_2.7mm_M2.5_DIN965_Pad

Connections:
Earth: MH801.1, MH802.1, MH803.1, MH804.1; also elsewhere on the board

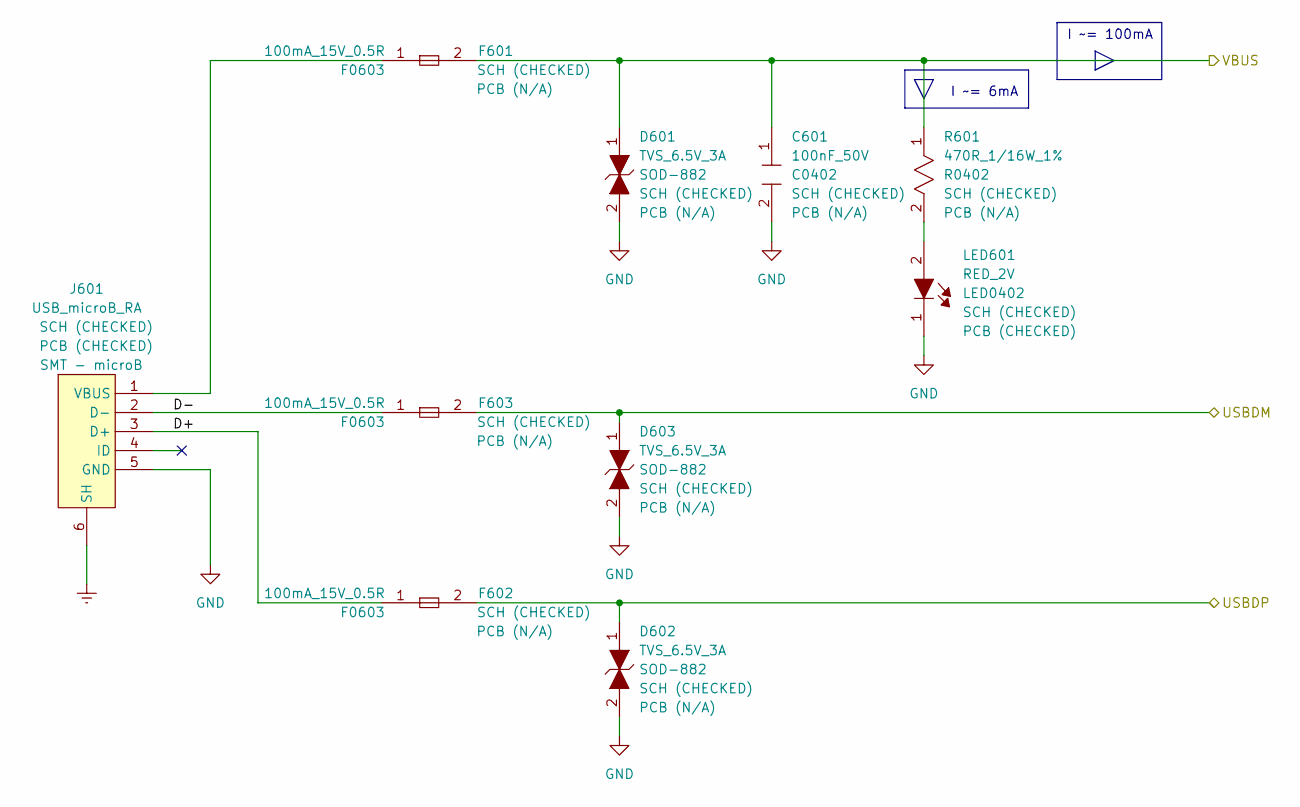
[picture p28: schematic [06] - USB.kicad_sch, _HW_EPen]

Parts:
C601: 100nF_50V; C_0402_1005Metric; Part Number (Manufactur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 GRM155R71H104KE14J
D601, D602, D603: TVS_6.5V_3A; CR_7PCT_L3F_TOS; Part Number (Vendor) 4786-GSEWT5B003TR-ND
F601, F602, F603: 100mA_15V_0.5R; Fuse_0603_1608Metric; Part Number (Vendor) 283-PTS060315V010TR-ND
J601: USB_microB_RA; USB_Micro-B_Amphenol_10118194_Horizontal; Part Number (Vendor) 609-4618-2-ND
LED601: RED_2V; LED_0402_1005Metric; Part Number (Vendor) 3147-B2841USD-20D001014U1930TR-ND
R601: 470R_1/16W_1%; R_0402_1005Metric; Part Number (Vendor) CR0402-FX-4700GLFTR-ND

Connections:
/BLOCK DIAGRAM/FT230X_DRIVER/USBDM: D603.1, F603.2; also elsewhere on the board
/BLOCK DIAGRAM/FT230X_DRIVER/USBDP: D602.1, F602.2; also elsewhere on the board
/BLOCK DIAGRAM/LDO +3V0DC/+5VDC: C601.1, D601.1, F601.2, R601.1; also elsewhere on the board
/BLOCK DIAGRAM/USB/D+: F602.1, J601.3 (D+)
/BLOCK DIAGRAM/USB/D-: F603.1, J601.2 (D-)
Earth: J601.6 (SH); also elsewhere on the board
GND: C601.2, D601.2, D602.2, D603.2, J601.5 (GND), LED601.1; also elsewhere on the board
unnamed: F601.1, J601.1 (VBUS)
unnamed: LED601.2, R601.2

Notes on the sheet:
I ~= 100mA
I ~= 6mA

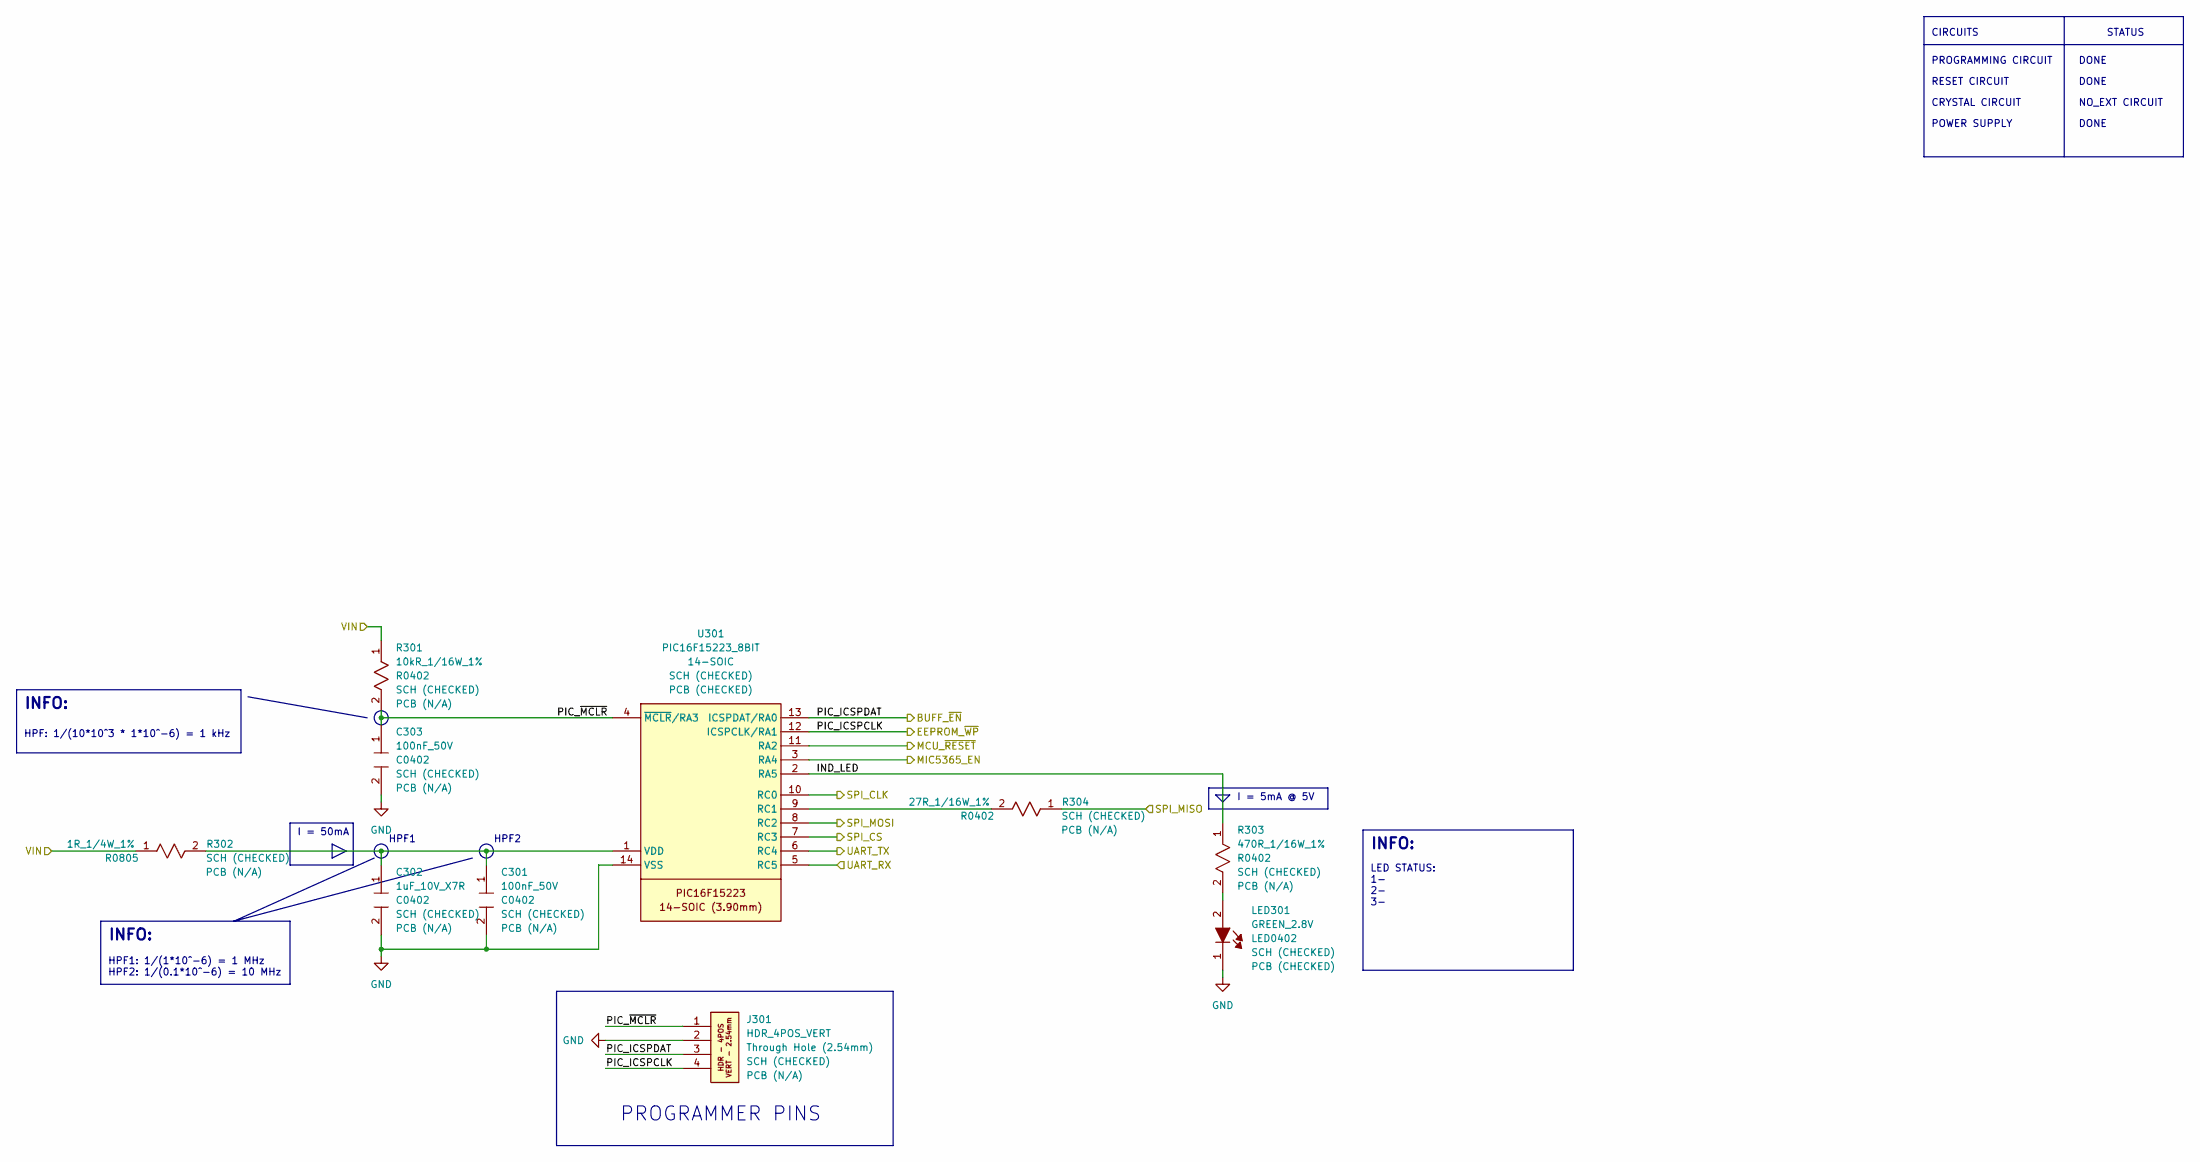
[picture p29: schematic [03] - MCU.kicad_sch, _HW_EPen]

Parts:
C301, C303: 100nF_50V; C_0402_1005Metric; Part Number (Manufactur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 GRM155R71H104KE14J
C302: 1uF_10V_X7R; C_0402_1005Metric; Part Number (Vendor) 490-GRM155Z71A105KE01DTR-ND
J301: HDR_4POS_VERT; PinHeader_1x04_P2.54mm_Vertical; Part Number (Vendor) 2057-PH1-04-UA-ND
LED301: GREEN_2.8V; LED_0402_1005Metric; Part Number (Vendor) 3147-B2841NG--05D000514U1930TR-ND
R301: 10kR_1/16W_1%; R_0402_1005Metric; Part Number (Vendor) CR0402-FX-1002GLFTR-ND
R302: 1R_1/4W_1%; R_0805_2012Metric; Part Number (Vendor) RNCP0805FTD1R00TR-ND
R303: 470R_1/16W_1%; R_0402_1005Metric; Part Number (Vendor) CR0402-FX-4700GLFTR-ND
R304: 27R_1/16W_1%; R_0402_1005Metric; Part Number (Vendor) CR0402-FX-27R0GLFTR-ND
U301: PIC16F15223_8BIT; SO-14_3.9x8.65mm_P1.27mm; Part Number (Vendor) 150-PIC16F15223-E/SL-ND

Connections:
/BLOCK DIAGRAM/FT230X_DRIVER/UART_RX: U301.6 (RC4); also elsewhere on the board
/BLOCK DIAGRAM/FT230X_DRIVER/UART_TX: U301.5 (RC5); also elsewhere on the board
/BLOCK DIAGRAM/LDO +3V0DC/+5VDC: R301.1, R302.1; also elsewhere on the board
/BLOCK DIAGRAM/LDO +3V0DC/MIC5365_PIN_EN: U301.3 (RA4); also elsewhere on the board
/BLOCK DIAGRAM/MCU/IND_LED: R303.1, U301.2 (RA5)
/BLOCK DIAGRAM/MCU/MCU_~RESET: U301.11 (RA2); also elsewhere on the board
/BLOCK DIAGRAM/MCU/PIC_ICSPCLK: J301.4, U301.12 (ICSPCLK/RA1); also elsewhere on the board
/BLOCK DIAGRAM/MCU/PIC_ICSPDAT: J301.3, U301.13 (ICSPDAT/RA0); also elsewhere on the board
/BLOCK DIAGRAM/MCU/PIC_~MCLR: C303.1, J301.1, R301.2, U301.4 (~MCLR/RA3)
/BLOCK DIAGRAM/MCU/SPI_CLK: U301.10 (RC0); also elsewhere on the board
/BLOCK DIAGRAM/MCU/SPI_CS: U301.7 (RC3); also elsewhere on the board
/BLOCK DIAGRAM/MCU/SPI_MISO: R304.1; also elsewhere on the board
/BLOCK DIAGRAM/MCU/SPI_MOSI: U301.8 (RC2); also elsewhere on the board
GND: C301.2, C302.2, C303.2, J301.2, LED301.1, U301.14 (VSS); also elsewhere on the board
unnamed: LED301.2, R303.2
unnamed: R304.2, U301.9 (RC1)
unnamed: C301.1, C302.1, R302.2, U301.1 (VDD)

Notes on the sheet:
HPF: 1/(10*10^3 * 1*10^-6) = 1 kHz
INFO:
I = 50mA
DONE
I = 5mA @ 5V
CRYSTAL CIRCUIT
HPF2
PROGRAMMER PINS
STATUS
LED STATUS: 1- 2- 3-
HPF1
POWER SUPPLY
NO_EXT CIRCUIT
HPF1: 1/(1*10^-6) = 1 MHz HPF2: 1/(0.1*10^-6) = 10 MHz
PROGRAMMING CIRCUIT
CIRCUITS
RESET CIRCUIT

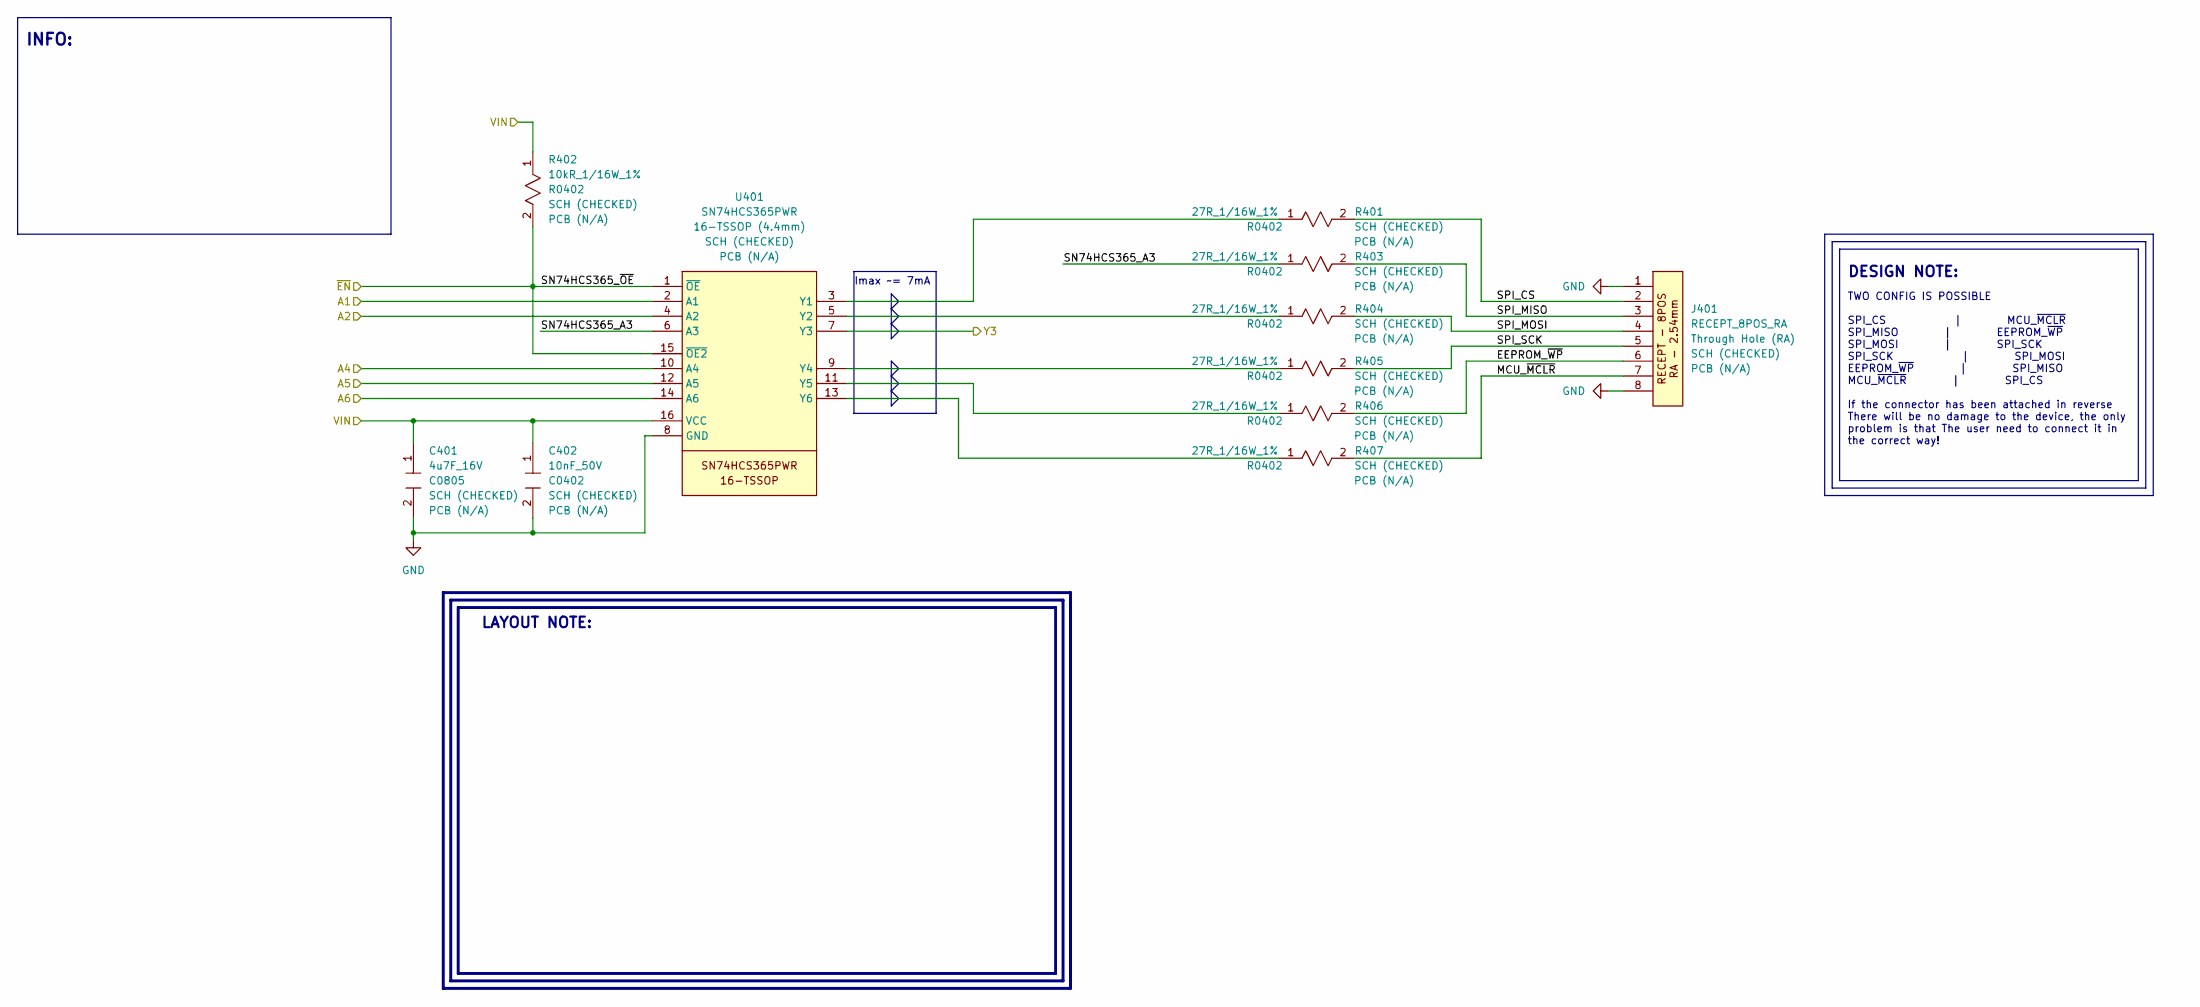
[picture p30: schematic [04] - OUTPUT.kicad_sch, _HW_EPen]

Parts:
C401: 4u7F_16V; C_0805_2012Metric; Part Number (Vendor) 490-14466-2-ND
C402: 10nF_50V; C_0402_1005Metric; Part Number (Vendor) 1276-1028-2-ND
J401: RECEPT_8POS_RA; PinSocket_1x08_P2.54mm_Horizontal; Part Number (Vendor) SAM1195-08-ND
R401, R403, R404, R405, R406, R407: 27R_1/16W_1%; R_0402_1005Metric; Part Number (Vendor) CR0402-FX-27R0GLFTR-ND
R402: 10kR_1/16W_1%; R_0402_1005Metric; Part Number (Vendor) CR0402-FX-1002GLFTR-ND
U401: SN74HCS365PWR; TSSOP-16_4.4x5mm_P0.65mm; Part Number (Vendor) 296-SN74HCS365PWRTR-ND

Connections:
/BLOCK DIAGRAM/LDO +3V0DC/+3VDC: C401.1, C402.1, R402.1, U401.16 (VCC); also elsewhere on the board
/BLOCK DIAGRAM/MCU/MCU_~RESET: U401.14 (A6); also elsewhere on the board
/BLOCK DIAGRAM/MCU/PIC_ICSPCLK: U401.12 (A5); also elsewhere on the board
/BLOCK DIAGRAM/MCU/PIC_ICSPDAT: R402.2, U401.1 (~OE), U401.15 (~OE2); also elsewhere on the board
/BLOCK DIAGRAM/MCU/SPI_CLK: U401.10 (A4); also elsewhere on the board
/BLOCK DIAGRAM/MCU/SPI_CS: U401.2 (A1); also elsewhere on the board
/BLOCK DIAGRAM/MCU/SPI_MISO: U401.7 (Y3); also elsewhere on the board
/BLOCK DIAGRAM/MCU/SPI_MOSI: U401.4 (A2); also elsewhere on the board
/BLOCK DIAGRAM/OUTPUT/EEPROM_~WP: J401.6, R406.2
/BLOCK DIAGRAM/OUTPUT/MCU_~MCLR: J401.7, R407.2
/BLOCK DIAGRAM/OUTPUT/SN74HCS365_A3: R403.1, U401.6 (A3)
/BLOCK DIAGRAM/OUTPUT/SPI_CS: J401.2, R401.2
/BLOCK DIAGRAM/OUTPUT/SPI_MISO: J401.3, R403.2
/BLOCK DIAGRAM/OUTPUT/SPI_MOSI: J401.4, R404.2
/BLOCK DIAGRAM/OUTPUT/SPI_SCK: J401.5, R405.2
GND: C401.2, C402.2, J401.1, J401.8, U401.8 (GND); also elsewhere on the board
unnamed: R401.1, U401.3 (Y1)
unnamed: R404.1, U401.5 (Y2)
unnamed: R405.1, U401.9 (Y4)
unnamed: R406.1, U401.11 (Y5)
unnamed: R407.1, U401.13 (Y6)

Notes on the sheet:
DESIGN NOTE:
TWO CONFIG IS POSSIBLE SPI_CS | MCU_~{MCLR} SPI_MISO | EEPROM_~{WP} SPI_MOSI | SPI_SCK SPI_SCK | SPI_MOSI EEPROM_~{WP} | SPI_MISO MCU_~{MCLR} | SPI_CS If the connector has been attached in reverse There will be no damage to the device, the only problem is that The user need to connect it in the cor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
INFO:
LAYOUT NOTE:
Imax ~= 7mA

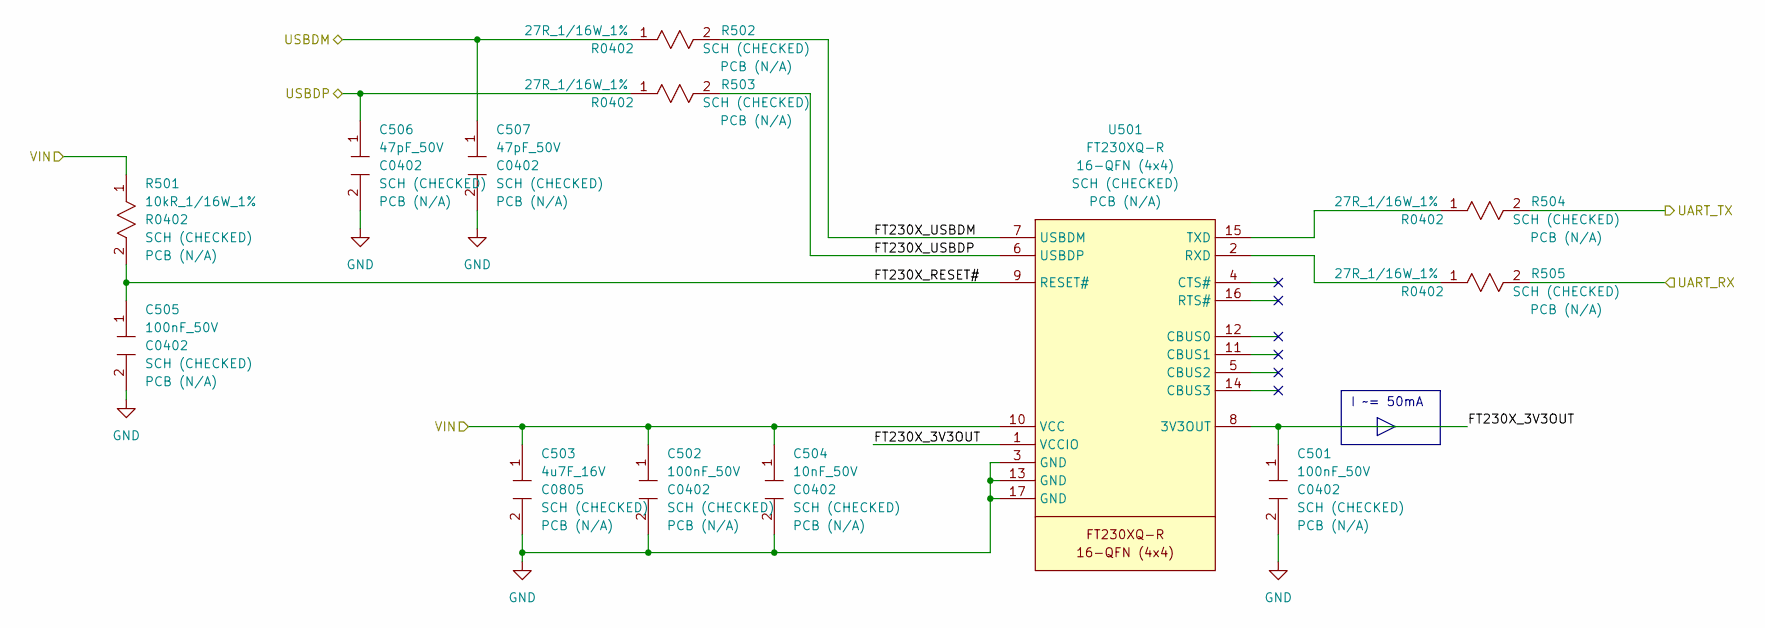
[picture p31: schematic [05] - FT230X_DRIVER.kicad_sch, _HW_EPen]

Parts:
C501, C502, C505: 100nF_50V; C_0402_1005Metric; Part Number (Manufactur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 GRM155R71H104KE14J
C503: 4u7F_16V; C_0805_2012Metric; Part Number (Vendor) 490-14466-2-ND
C504: 10nF_50V; C_0402_1005Metric; Part Number (Vendor) 1276-1028-2-ND
C506, C507: 47pF_50V; C_0402_1005Metric; Part Number (Vendor) 399-C0402C470J5RACAUTOTR-ND
R501: 10kR_1/16W_1%; R_0402_1005Metric; Part Number (Vendor) CR0402-FX-1002GLFTR-ND
R502, R503, R504, R505: 27R_1/16W_1%; R_0402_1005Metric; Part Number (Vendor) CR0402-FX-27R0GLFTR-ND
U501: FT230XQ-R; QFN-16-1EP_4x4mm_P0.65mm_EP2.1x2.1mm_ThermalVias; Part Number (Vendor) 768-1130-2-ND

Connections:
/BLOCK DIAGRAM/FT230X_DRIVER/FT230X_3V3OUT: C501.1, U501.1 (VCCIO), U501.8 (3V3OUT)
/BLOCK DIAGRAM/FT230X_DRIVER/FT230X_RESET#: C505.1, R501.2, U501.9 (RESET#)
/BLOCK DIAGRAM/FT230X_DRIVER/FT230X_USBDM: R502.2, U501.7 (USBDM)
/BLOCK DIAGRAM/FT230X_DRIVER/FT230X_USBDP: R503.2, U501.6 (USBDP)
/BLOCK DIAGRAM/FT230X_DRIVER/UART_RX: R505.2; also elsewhere on the board
/BLOCK DIAGRAM/FT230X_DRIVER/UART_TX: R504.2; also elsewhere on the board
/BLOCK DIAGRAM/FT230X_DRIVER/USBDM: C507.1, R502.1; also elsewhere on the board
/BLOCK DIAGRAM/FT230X_DRIVER/USBDP: C506.1, R503.1; also elsewhere on the board
/BLOCK DIAGRAM/LDO +3V0DC/+5VDC: C502.1, C503.1, C504.1, R501.1, U501.10 (VCC); also elsewhere on the board
GND: C501.2, C502.2, C503.2, C504.2, C505.2, C506.2, C507.2, U501.3 (GND), U501.13 (GND), U501.17 (GND); also elsewhere on the board
unnamed: R505.1, U501.2 (RXD)
unnamed: R504.1, U501.15 (TXD)

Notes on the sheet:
I ~= 50mA

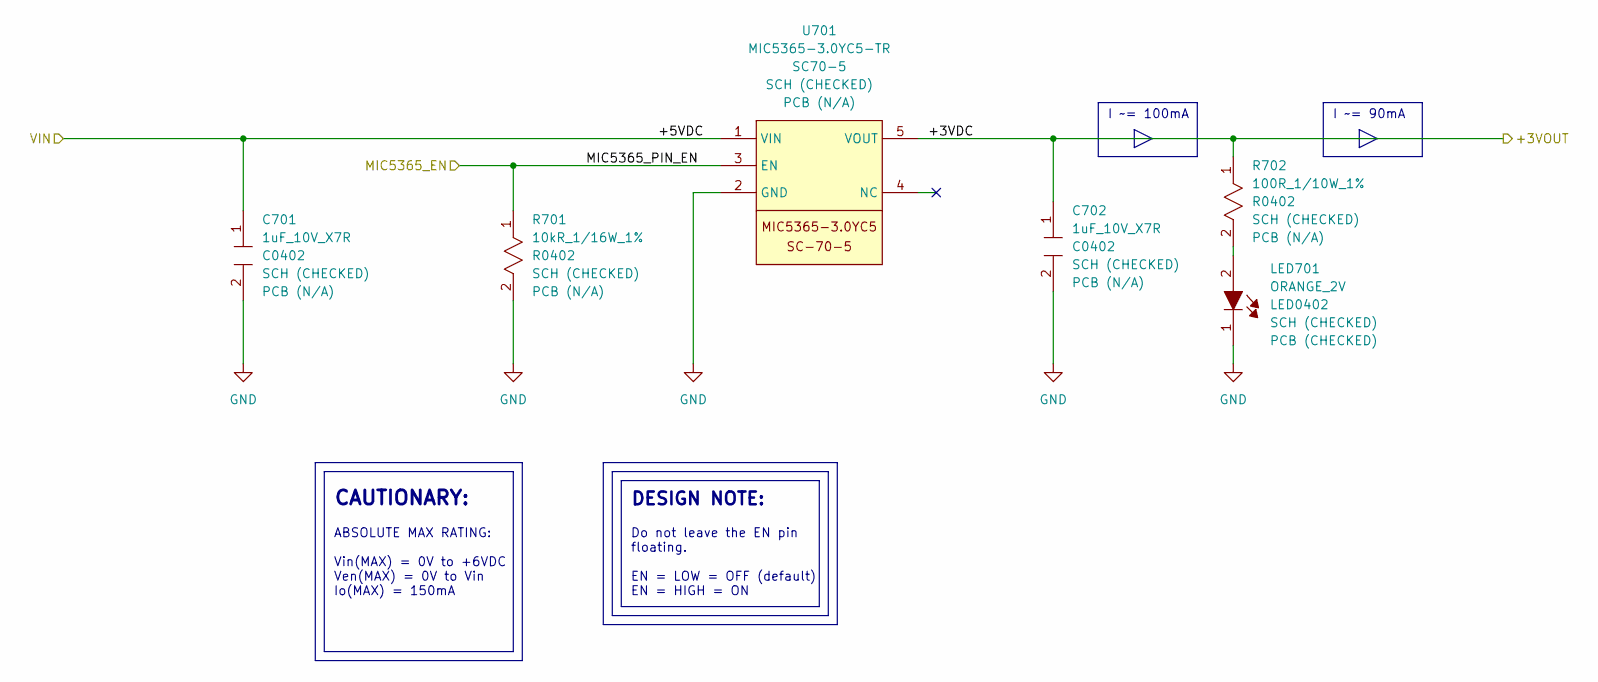
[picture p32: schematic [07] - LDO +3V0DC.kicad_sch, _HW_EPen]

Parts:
C701, C702: 1uF_10V_X7R; C_0402_1005Metric; Part Number (Vendor) 490-GRM155Z71A105KE01DTR-ND
LED701: ORANGE_2V; LED_0402_1005Metric; Part Number (Vendor) 3147-B2841UD--20D000614U1930TR-ND
R701: 10kR_1/16W_1%; R_0402_1005Metric; Part Number (Vendor) CR0402-FX-1002GLFTR-ND
R702: 100R_1/10W_1%; R_0402_1005Metric; Part Number (Vendor) 2019-RK73H1ETTP1000FTR-ND
U701: MIC5365-3.0YC5-TR; SOT-353_SC-70-5; Part Number (Vendor) 576-3191-2-ND

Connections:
/BLOCK DIAGRAM/LDO +3V0DC/+3VDC: C702.1, R702.1, U701.5 (VOUT); also elsewhere on the board
/BLOCK DIAGRAM/LDO +3V0DC/+5VDC: C701.1, U701.1 (VIN); also elsewhere on the board
/BLOCK DIAGRAM/LDO +3V0DC/MIC5365_PIN_EN: R701.1, U701.3 (EN); also elsewhere on the board
GND: C701.2, C702.2, LED701.1, R701.2, U701.2 (GND); also elsewhere on the board
unnamed: LED701.2, R702.2

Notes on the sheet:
CAUTIONARY:
I ~= 100mA
I ~= 90mA
Do not leave the EN pin floating. EN = LOW = OFF (default) EN = HIGH = ON
DESIGN NOTE:
ABSOLUTE MAX RATING: Vin(MAX) = 0V to +6VDC Ven(MAX) = 0V to Vin Io(MAX) = 150mA

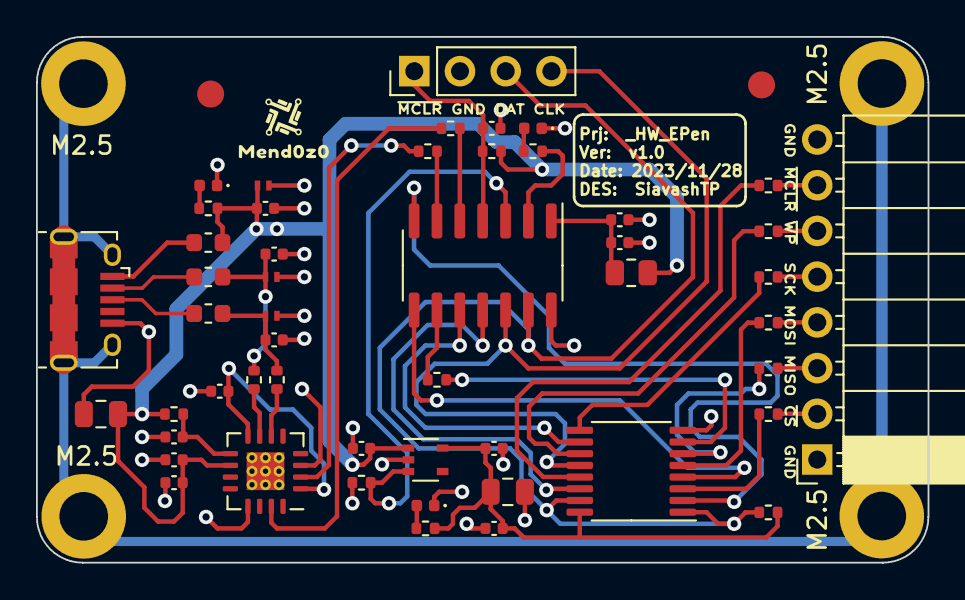
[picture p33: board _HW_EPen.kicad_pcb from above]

Board: 2 copper layers, 49.5 x 29.2 mm, 57 parts (0 on the bottom side), 44 nets.

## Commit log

2023-11-20 Adding folder
    [_ProjectTemplate_.kicad_sch]
2023-11-22 Uploading HW Project file
    [_HW_EPaper.kicad_pcb, _HW_EPaper.kicad_sch, _HW_EPen.kicad_pcb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]
2023-11-25 Working on EPen Schematic
    [[02] - BLOCK DIAGRAM.kicad_sch, [03] - MCU.kicad_sch, [04] - OUTPUT.kicad_sch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]
2023-11-27 More progress on EPen Hardware
    [[02] - BLOCK DIAGRAM.kicad_sch, [03] - MCU.kicad_sch, [04] - OUTPUT.kicad_sch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]
2023-11-28 _HW_EPen is ready to be worked for layout
    [[02] - BLOCK DIAGRAM.kicad_sch, [03] - MCU.kicad_sch, [04] - OUTPUT.kicad_sch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]
2023-11-28 Working on PCB layout
    [[05] - FT230X_DRIVER.kicad_sch]
2023-11-29 EPen layout is almost done
    [[08] - MECHANICAL PARTS.kicad_sch, _HW_EPen.kicad_pcb]
2023-11-29 Working on EPaper Schematic
    [[02] - BLOCK DIAGRAM.kicad_sch, [03] - MCU.kicad_sch, [04] - SERIAL FLASH.kicad_sch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]
2023-12-03 Working on E-Paper schematic
    [[02] - BLOCK DIAGRAM.kicad_sch, [05] - INPUT CIRCUIT.kicad_sch, [10] - BATTERY CIRCUIT.kicad_sch]
2023-12-04 EPaper schematic is almost done...
    [[02] - BLOCK DIAGRAM.kicad_sch, [04] - SERIAL FLASH.kicad_sch, [07] - DISPLAY DRIVER.kicad_sch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]
2023-12-16 Latest update
    [[02] - BLOCK DIAGRAM.kicad_sch, [03] - MCU.kicad_sch, [04] - SERIAL FLASH.kicad_sch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]
2023-12-18 Working on epaper hardware
    [[02] - BLOCK DIAGRAM.kicad_sch, [03] - MCU.kicad_sch, [04] - SERIAL FLASH.kicad_sch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]
2023-12-18 Hardware is almost done
    [[04] - SERIAL FLASH.kicad_sch, [05] - INPUT CIRCUIT.kicad_sch, [06] - USB.kicad_sch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]
2023-12-19 Updating file templates and structures...
    [[02] - BLOCK DIAGRAM.kicad_sch, [03] - MCU.kicad_sch, [04] - OUTPUT.kicad_sch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]
2023-12-20 Updating Hardware File structures
    [[02] - BLOCK DIAGRAM.kicad_sch, [03] - MCU.kicad_sch, [03] - MICROCONTROLLER.kicad_sch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]
